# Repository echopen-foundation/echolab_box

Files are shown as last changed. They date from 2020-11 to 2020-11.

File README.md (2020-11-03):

---

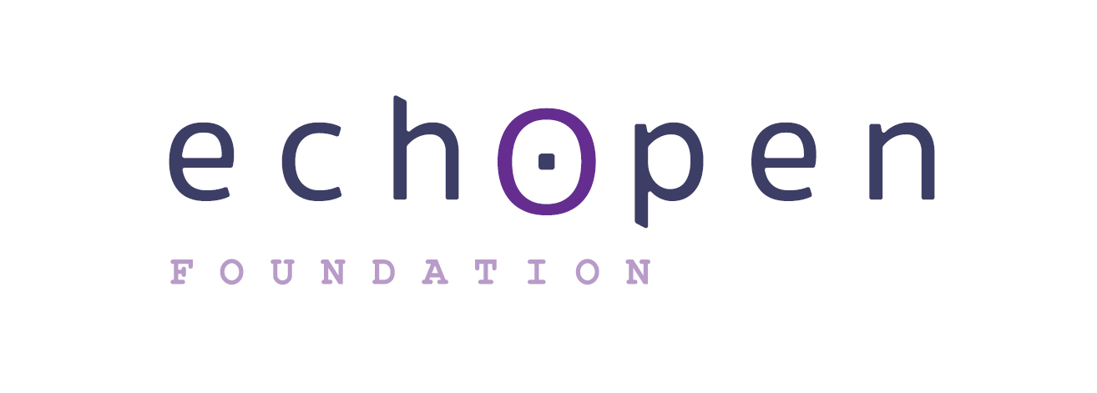
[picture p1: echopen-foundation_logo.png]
[](http://www.echopen.org)

---

# echʘlab Box

This project presents box containing all necessary components to play with ultrasound.

Find source files here : https://github.com/echopen-foundation/echolab_box

Find documentation here : https://github.com/echopen-foundation/echolab_box/wiki

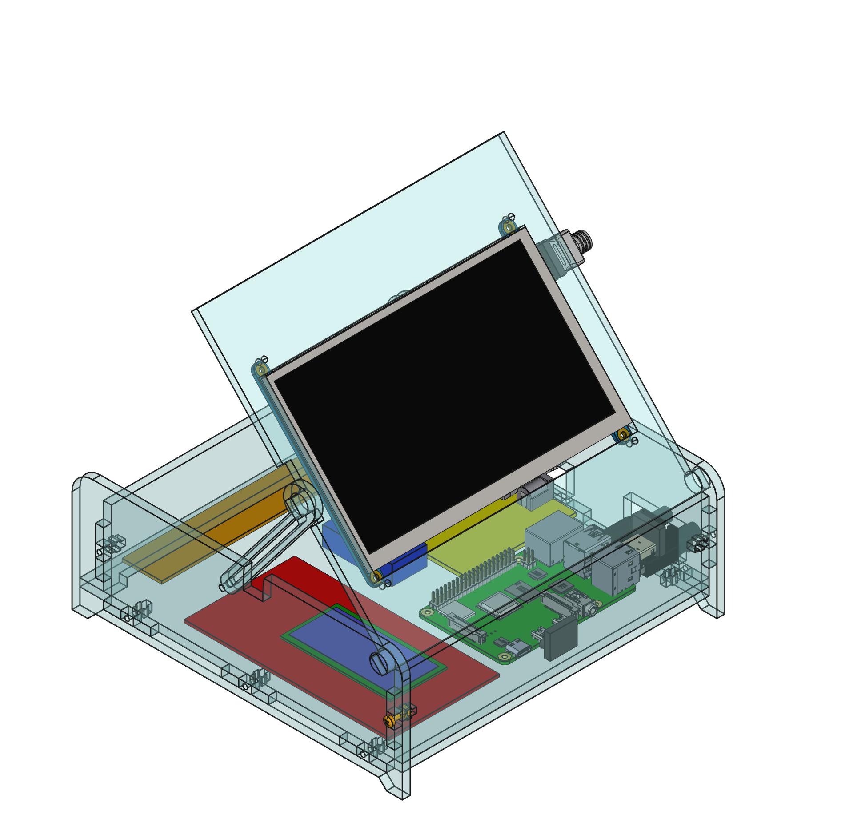
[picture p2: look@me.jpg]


---

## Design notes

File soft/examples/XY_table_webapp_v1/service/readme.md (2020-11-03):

# Installation as a service

from : http://www.diegoacuna.me/how-to-run-a-script-as-a-service-in-raspberry-pi-raspbian-jessie/
and : https://wiki.archlinux.org/index.php/systemd

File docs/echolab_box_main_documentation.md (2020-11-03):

# echolab_box

## Introduction

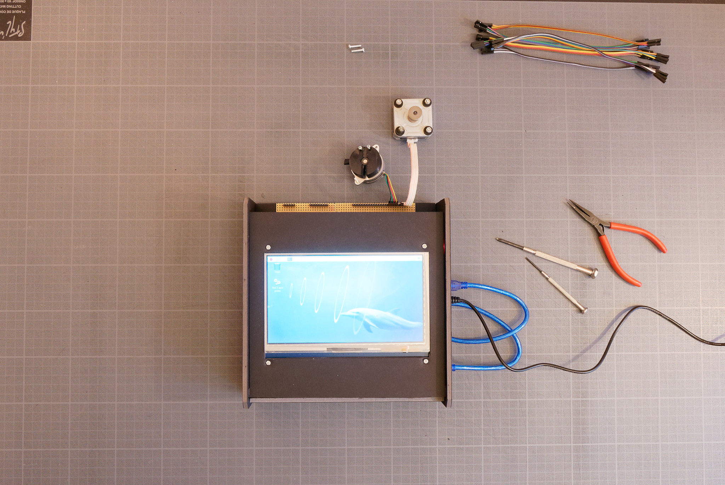
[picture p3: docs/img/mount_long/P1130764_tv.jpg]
Main Picture


| Prerequisite | None |
| :--- | --- |
| **Duration** | 1/2 day |
| **Cost** | 800 - 900 € |
| **Open-source License Software** | BSD3 License |
| **Open-source License Hardware** | EchOpen License |

echolab_box is the first step of the echolab project by echOpen. The idea of echolab (EchOpen Lab Kit) project is to capitalize on all the previous contribution of the community and design an open-source modular hardware  "EchOpen Lab Kit" which enable everyone to make their own acoustic, software and firmware experiment. We want to develop a full range of components compatible and combinable with one another in order to build a custom lab. echolab_box is the core module conceived as a test bench on which you can plug devices such as 2D table, custom ultrasound card, custom transducers...

## Design files

The only design files needed to build echolab_scope are the casing files as all the other component are mechanic or electronic parts available on the market.

| Title  | Original files | Reading files | Design tool |
| --- | --- | --- | --- |
| Casing | [Link to originals](../meca/echolab_box_v3.fcstd) | [Link to reading files](../meca/build/casing_to_print.pdf) | [FreeCad](https://www.freecadweb.org/?lang=fr) |

*Original files: files used to make modifications on the project*

*Export files: files that can be opened and imported by other programs or softwares (STEP, IGES...)*

*Reading files: files used to study or produce without modifications (PDF, STL...)*

## Software and firmware

| Source code | Compilation process | State |
| --- | --- | --- |
| [echolab_box/soft/src](../soft/src) | Python 3 | In progress |

## Nomenclature

| Designation | Quantity | Description | Supplier  | Price/unit (€ TTC) | Datasheet |
| --- | --- | --- | --- | --- | --- |
| Software Controller  | 1 | Controller Rpi - 4GB | LetMeKnow | 69 | [Link to datasheet]([https://letmeknow,fr/shop/fr/cartes-officielles/1782-raspberry-pi-4-4gb-4053199971756,html](https://letmeknow.fr/shop/fr/cartes-officielles/1782-raspberry-pi-4-4gb-4053199971756.html)) |
| Touch screen | 1 | Screen waveshark 7 inch Capacitive Touch Screen HDMI LCD 1024 * 600 | Amazon | 60,96 | [Link to datasheet](https://www.amazon.fr/waveshare-Capacitive-Touchscreen-Display-LCD/dp/B07PK26D9H/ref=sr_1_6?__mk_fr_FR=ÅMÅŽÕÑ&keywords=screen%2B7%2Bhdmi&qid=1568879840&s=gateway&sr=8-6&th=1) |
| Ultrasound card | 1 | Ultrasound card open-source | echOpen | 600 | |
| CNC card | 1 | CNC card KEYESTUDIO Grbl Blister CNC carte contrôleur DIY | Amazon | 21,59 | [Link to datasheet](https://www.amazon.fr/keyestudio-contrôleur-Microcontrôleur-automatique-Fantasque/dp/B07D8LN386/ref=sr_1_17?__mk_fr_FR=ÅMÅŽÕÑ&keywords=cnc+shield&qid=1568881247&s=gateway&sr=8-17) |
| 5V Down power supply | 2 | 5V regulator DFR0571 3 A maxi | GoTronic  | 3,7 | [Link to datasheet](https://www.gotronic.fr/art-regulateur-5-vcc-dfr0571-29558.htm) |
| 12V Power supply | 1 | 12V Power supply | | | |
| Connections | 1 | HDMI display | Adafruit  | 5,88 | https://www,adafruit,com/product/3549 |
| Connections | 1 | HDMI RPi | Adafruit  | 5,88 | https://www,adafruit,com/product/3557 |
| Connections | 2 | Wire 20 cm | Adafruit  | 1,76 | https://www,adafruit,com/product/3561 |
| Connections | 2 | µUSB display and RPi | Adafruit  | 4,48 | https://www,adafruit,com/product/4105 |
| Connections | | PCB connector | | | |
| Casing | | Casing | | | |
| Fasteners | | Fasteners | | | |

## Assembly

| List of tools needed | Where to find it? |
| --- | --- |
| Screw driver | *(Optional)* |
| In Progress... | |

| Picture | Assembly instructions |
| --- | --- |
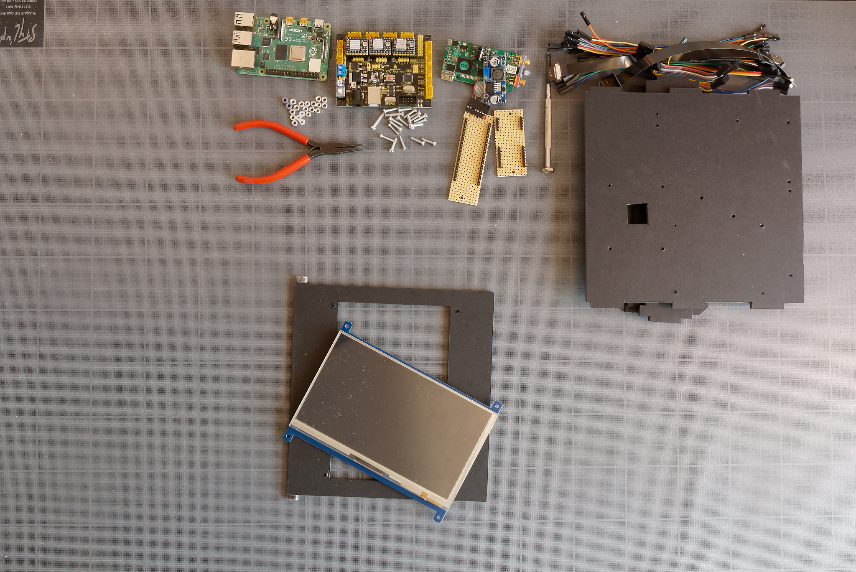
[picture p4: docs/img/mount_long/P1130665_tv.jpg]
Step 1 Picture
|  | Hardware components  We are using M2.5x12 screws and M2.5 nuts for all the assembly |
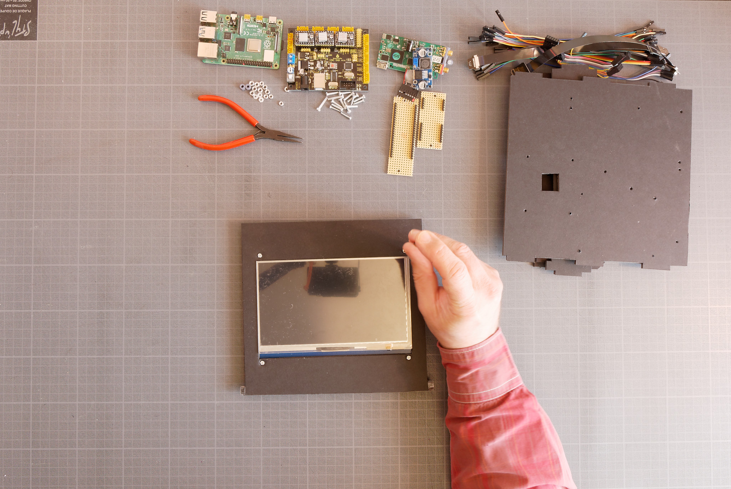
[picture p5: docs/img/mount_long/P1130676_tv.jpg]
Step 2 Picture
|  | Mount the touch screen on the top part of the box |
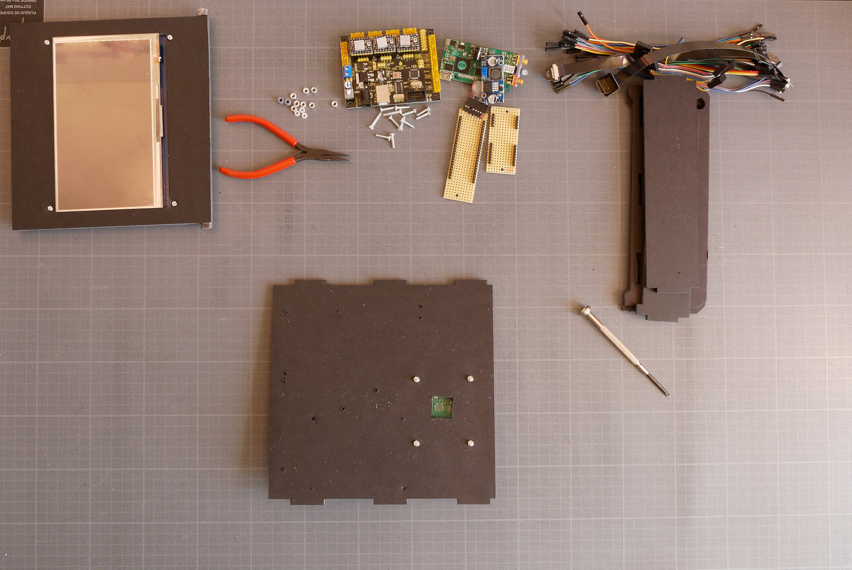
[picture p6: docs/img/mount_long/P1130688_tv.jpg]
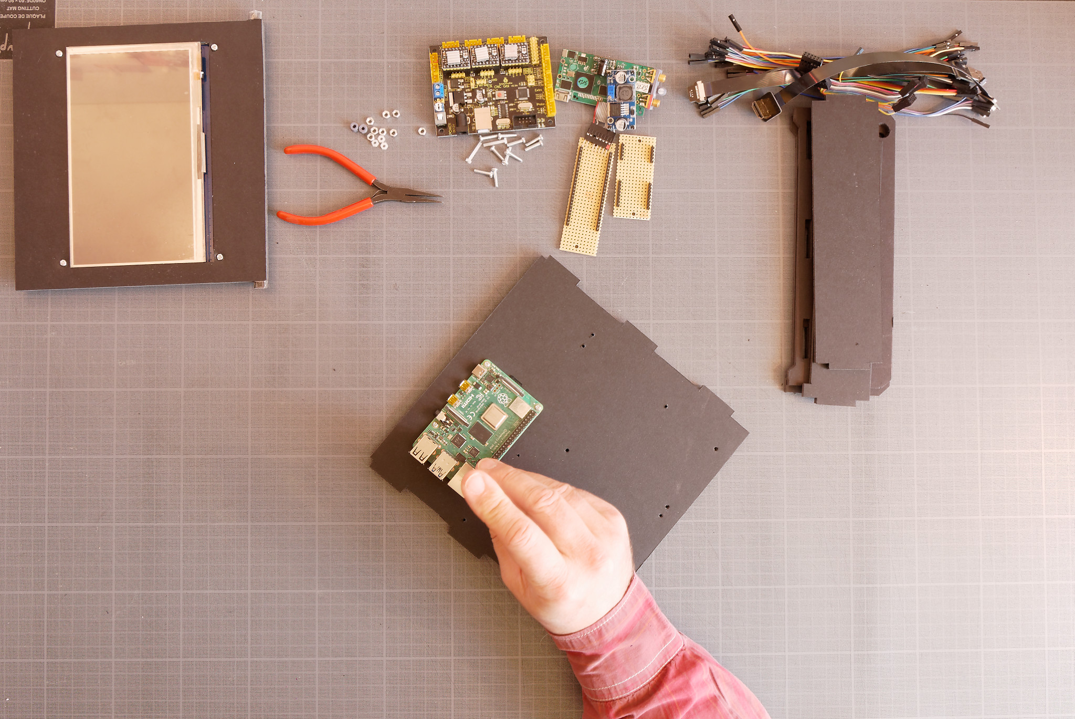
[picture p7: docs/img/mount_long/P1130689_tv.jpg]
|  | Mount the Raspberry Pi controller on the base of the casing |
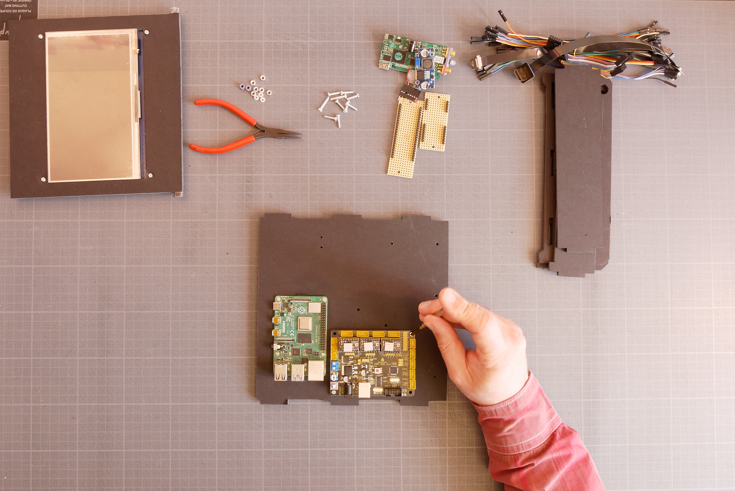
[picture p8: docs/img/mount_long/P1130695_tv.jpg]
Step 4 Picture
|  | Mount the CNC card |
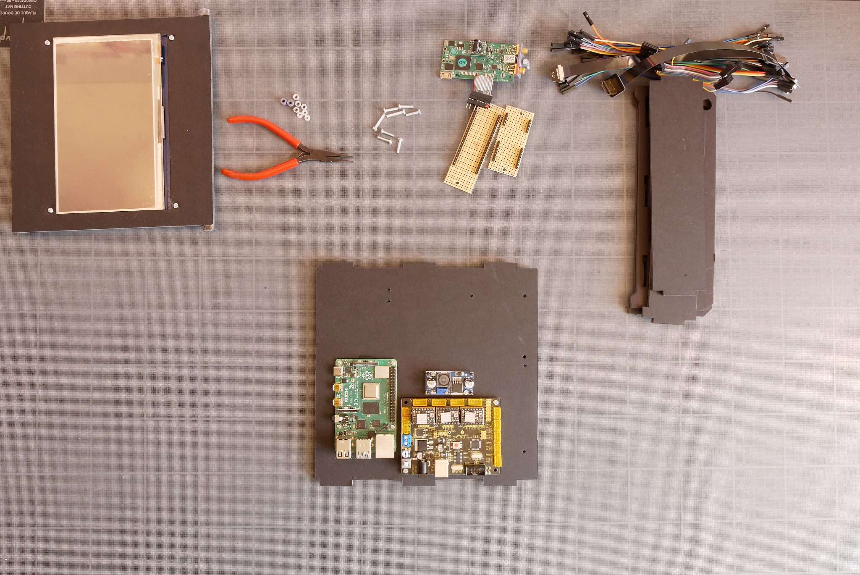
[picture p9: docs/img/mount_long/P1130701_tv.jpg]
Step 5 Picture
|  | Mount the 5V Step down power supply |
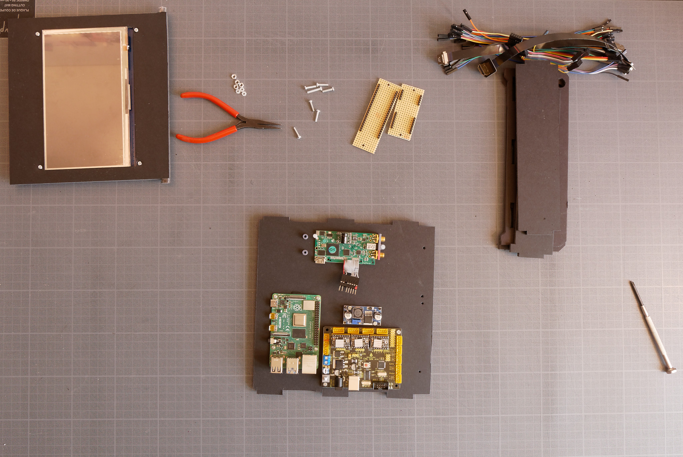
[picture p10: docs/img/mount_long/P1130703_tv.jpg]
Step 6 Picture
|  | Mount the ultrasound card. This model is a US SPI (can be replaced by another open-source model) |
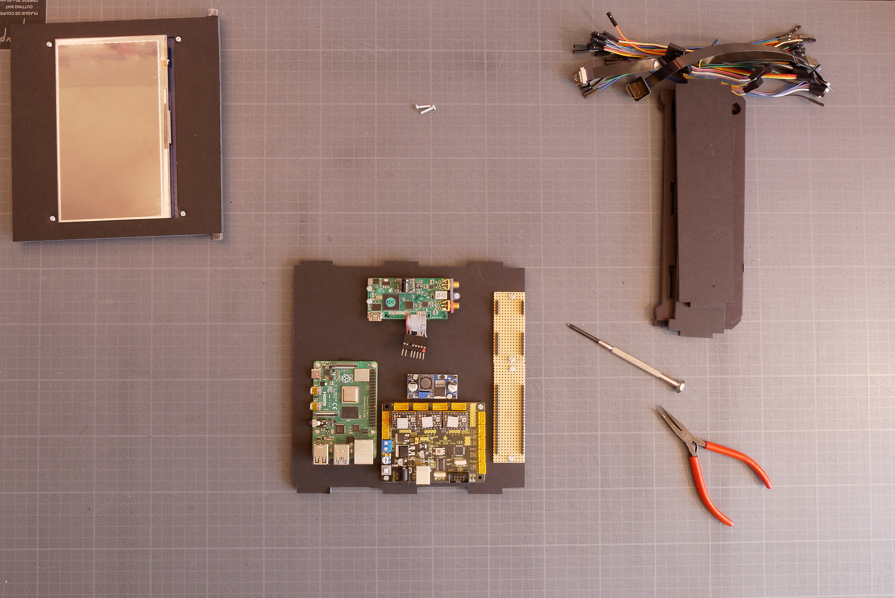
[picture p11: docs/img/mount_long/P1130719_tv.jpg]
Step 7 Picture
|  | Mount the connector board |
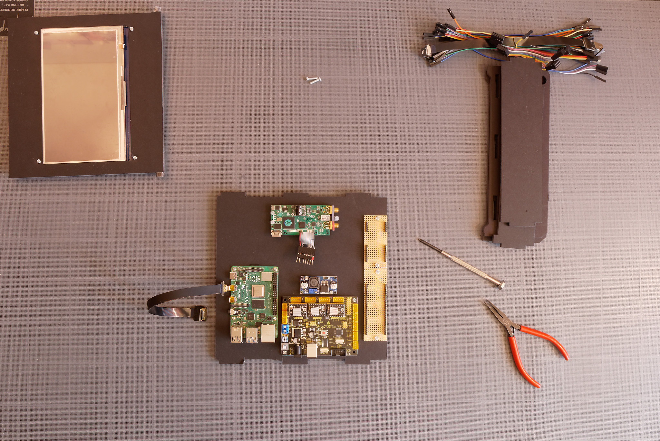
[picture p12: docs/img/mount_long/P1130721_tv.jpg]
Step 8 Picture
|  | Connect the HDMI wire to the Raspberry Pi |
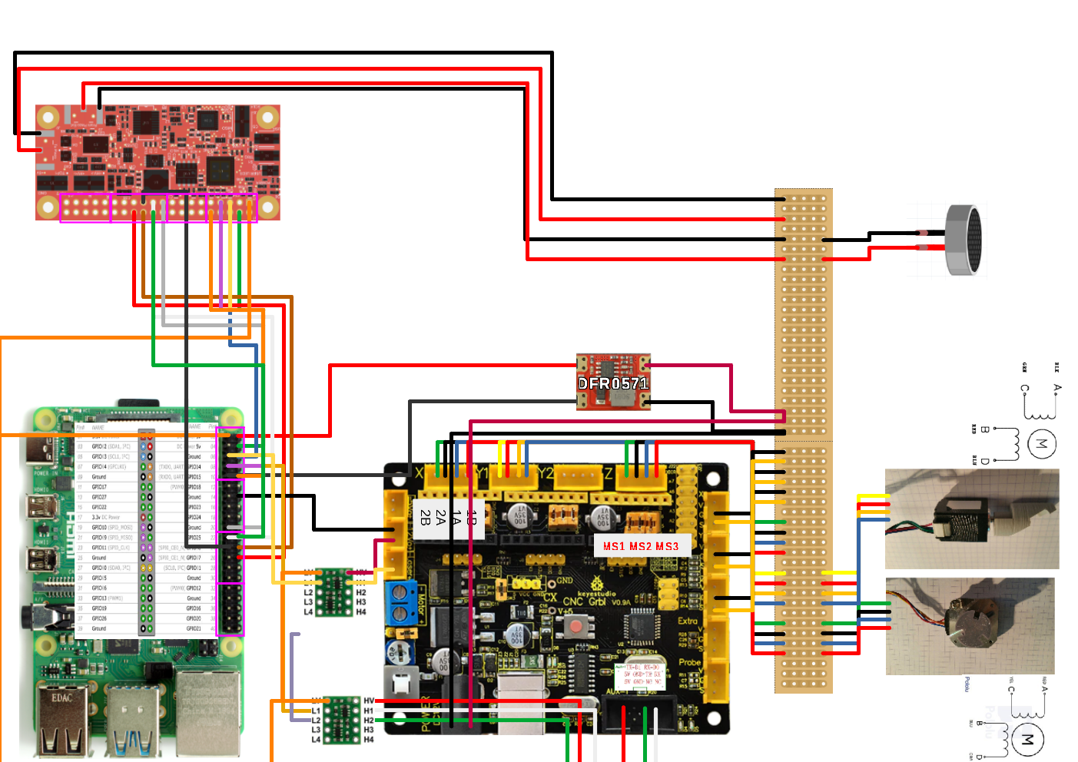
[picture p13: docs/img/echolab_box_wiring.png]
Step 9 Picture
|  | We are now going to connect all the components following this wiring scheme |
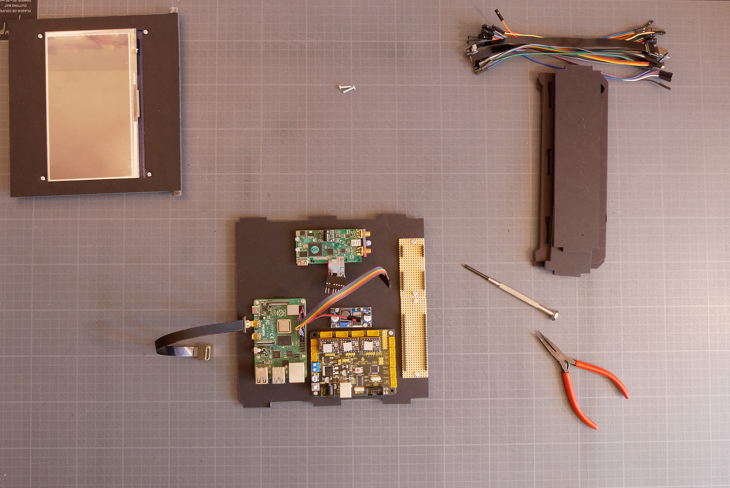
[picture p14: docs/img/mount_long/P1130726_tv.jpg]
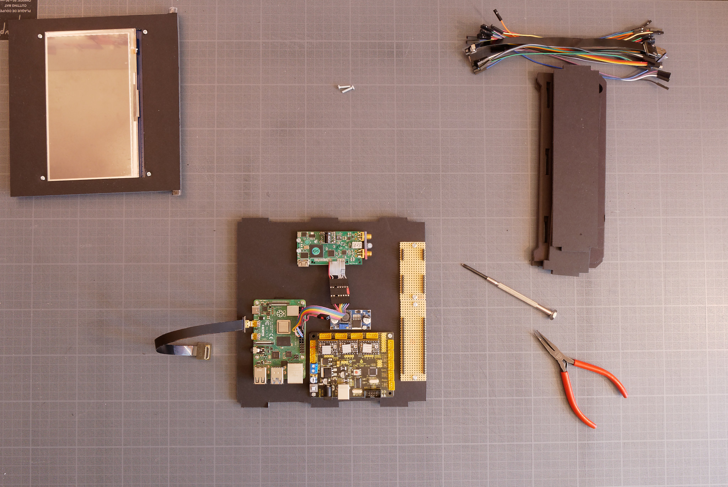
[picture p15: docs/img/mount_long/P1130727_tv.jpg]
|  | Connect the RPi to the ultrasound board |
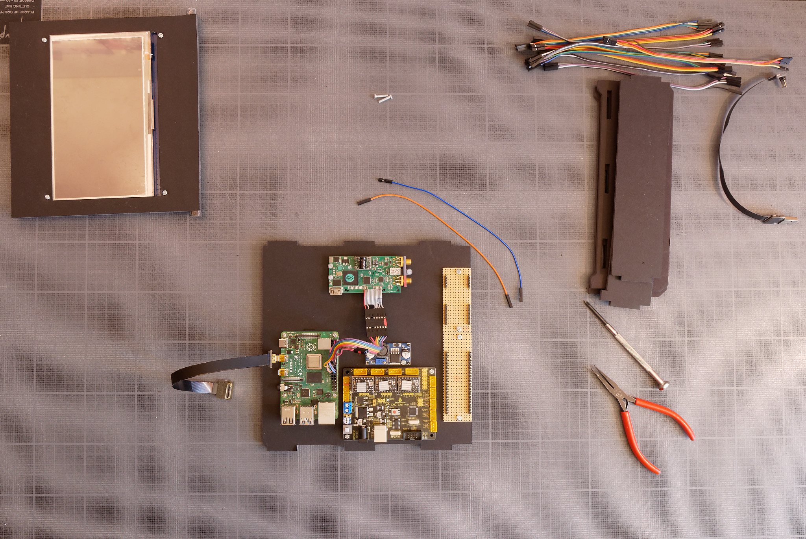
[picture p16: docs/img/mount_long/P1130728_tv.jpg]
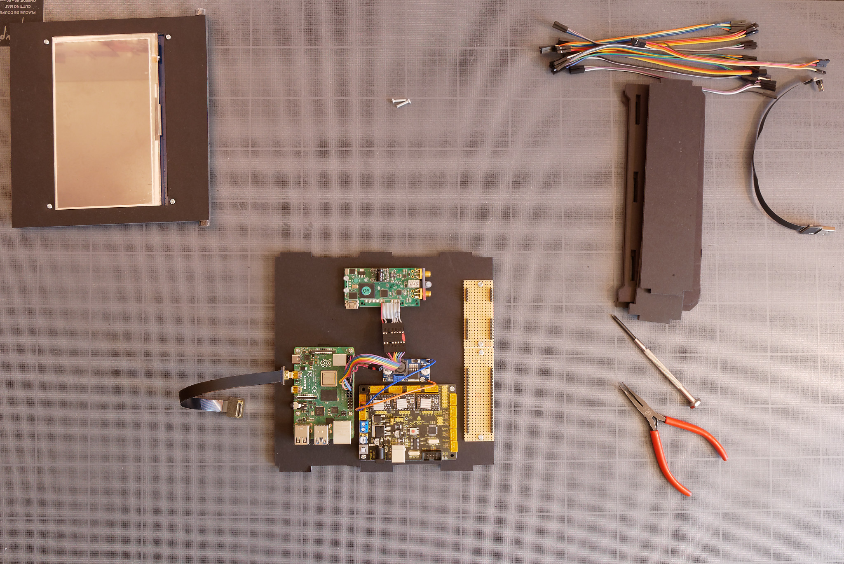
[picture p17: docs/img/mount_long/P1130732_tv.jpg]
|  | Then connect the CNC card to the 5V Step down power supply |
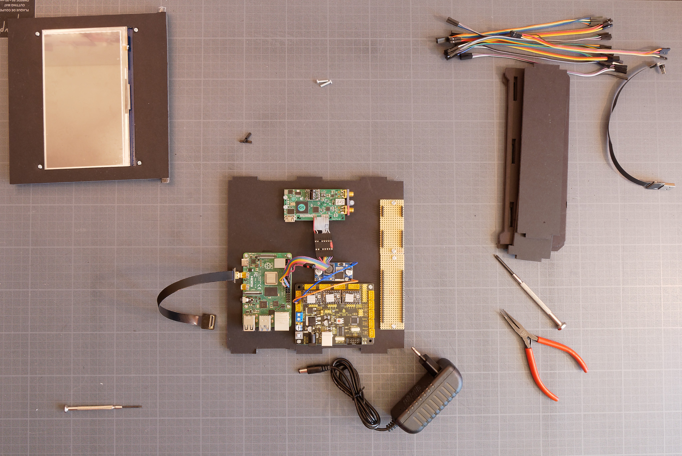
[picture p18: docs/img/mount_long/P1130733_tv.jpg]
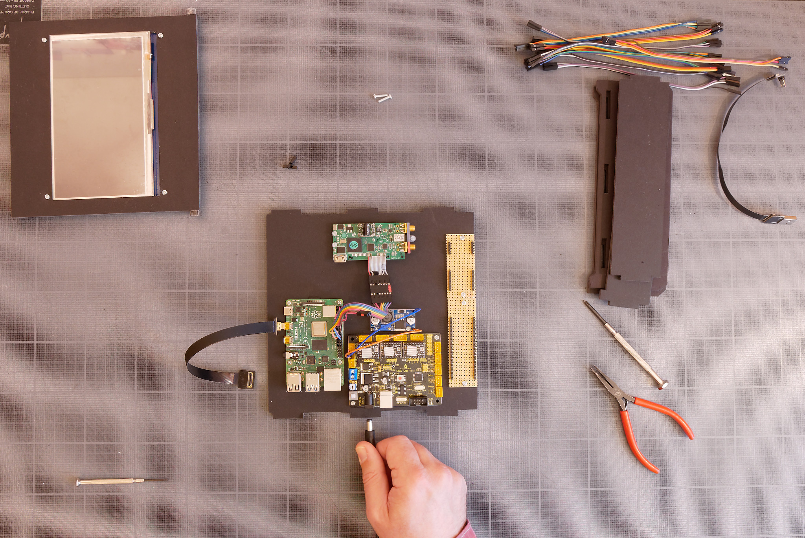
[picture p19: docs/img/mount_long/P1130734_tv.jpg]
|  | Connect the 12V Power supply to the CNC card |
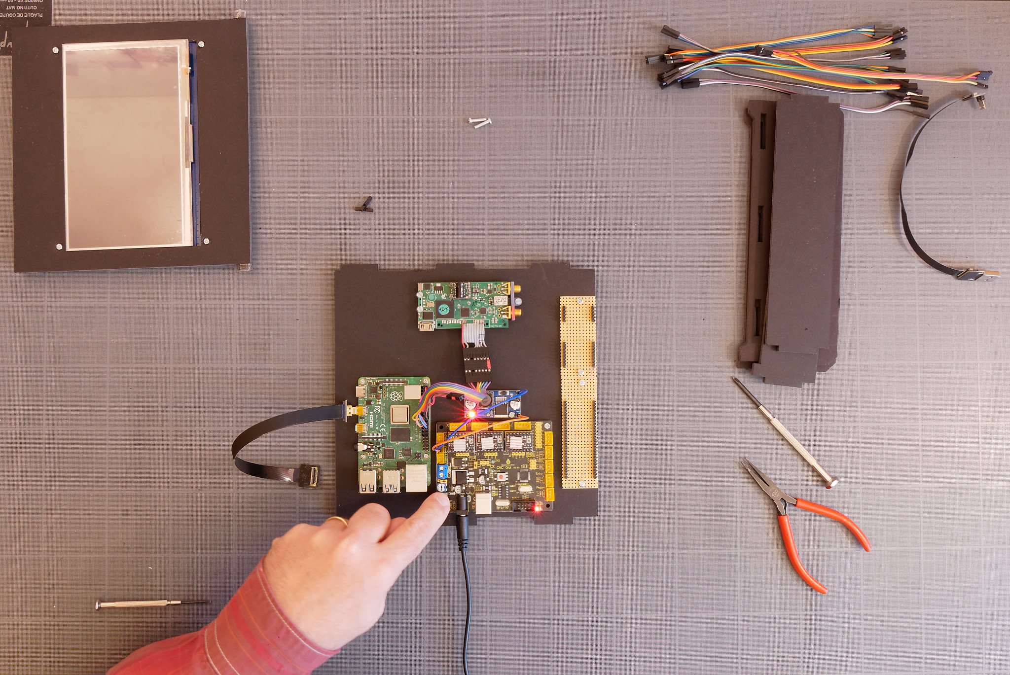
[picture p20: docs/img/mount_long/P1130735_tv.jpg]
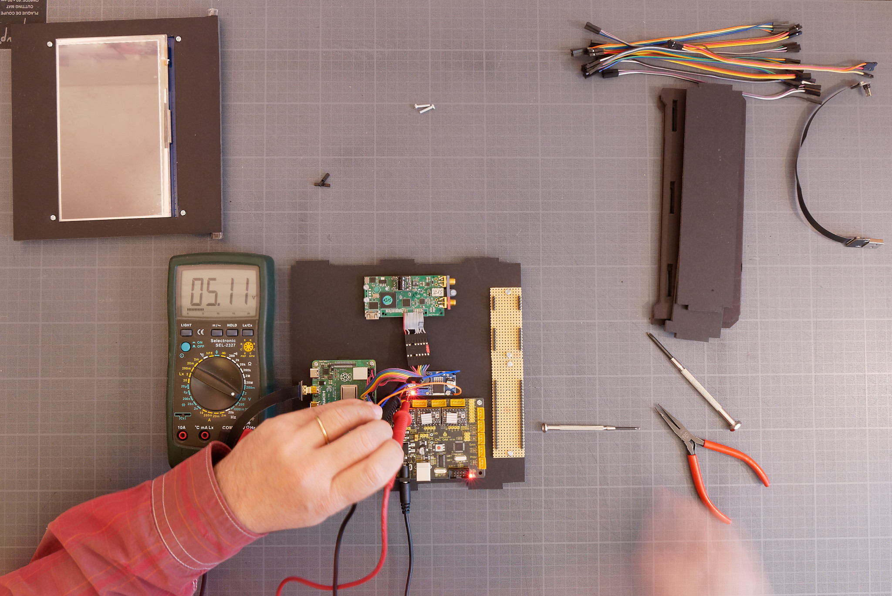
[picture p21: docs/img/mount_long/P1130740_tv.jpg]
|  | Set the Step down power supply to 5V prior to connect the RPi |
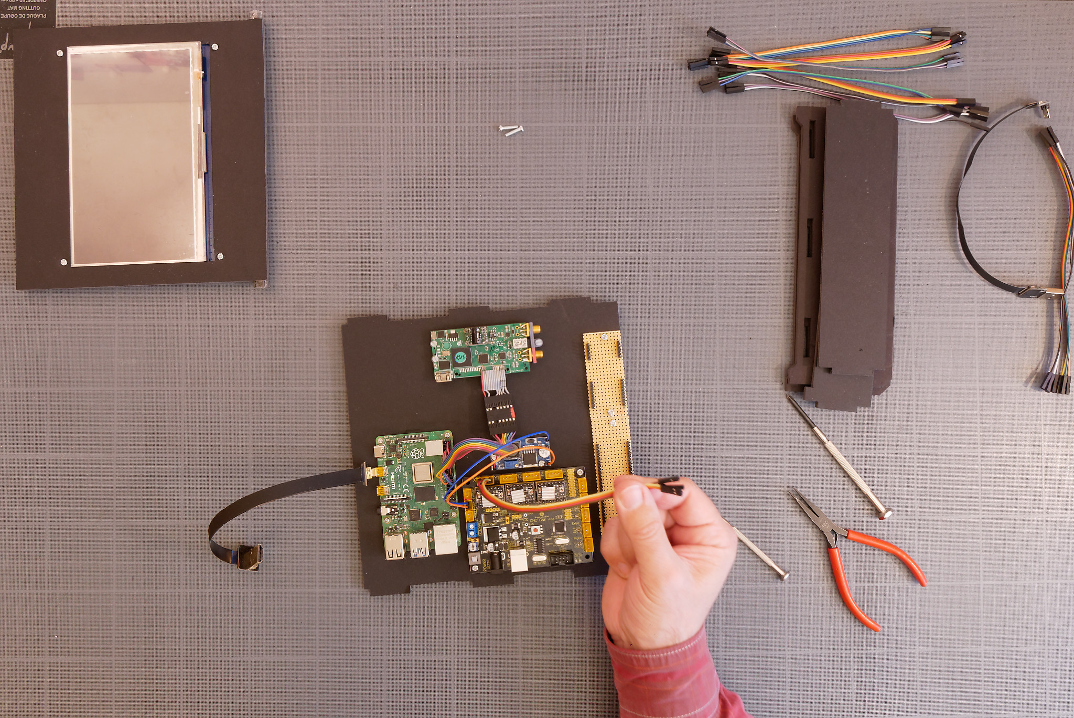
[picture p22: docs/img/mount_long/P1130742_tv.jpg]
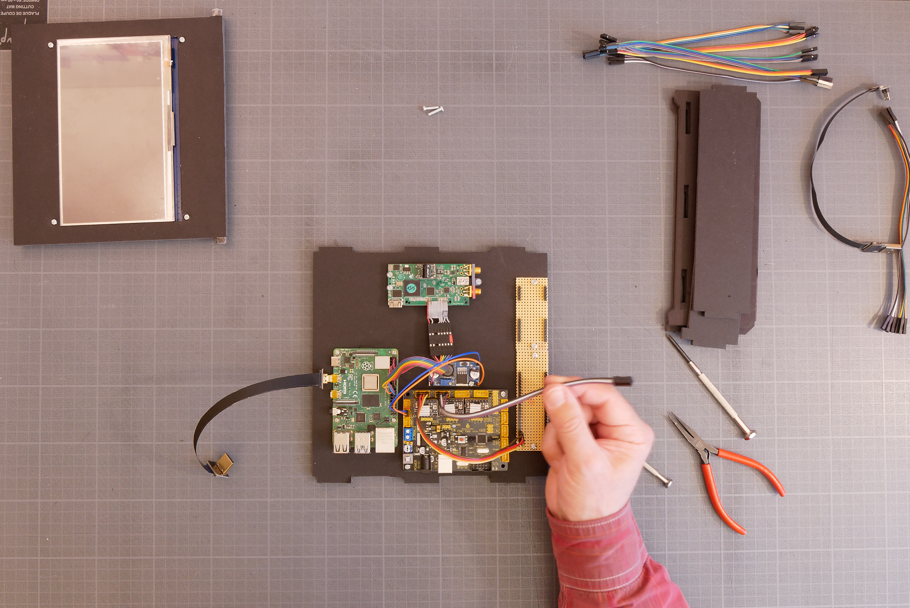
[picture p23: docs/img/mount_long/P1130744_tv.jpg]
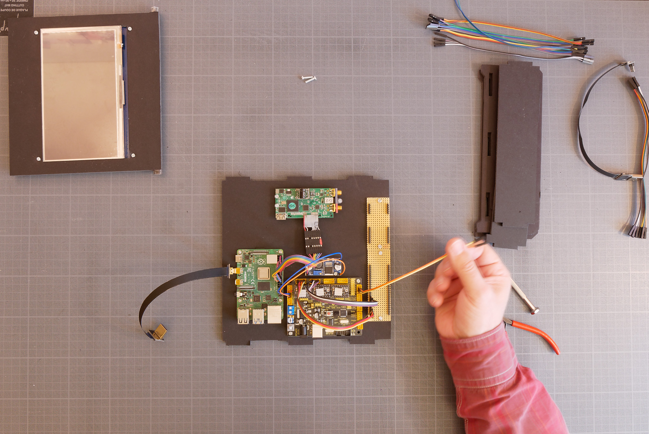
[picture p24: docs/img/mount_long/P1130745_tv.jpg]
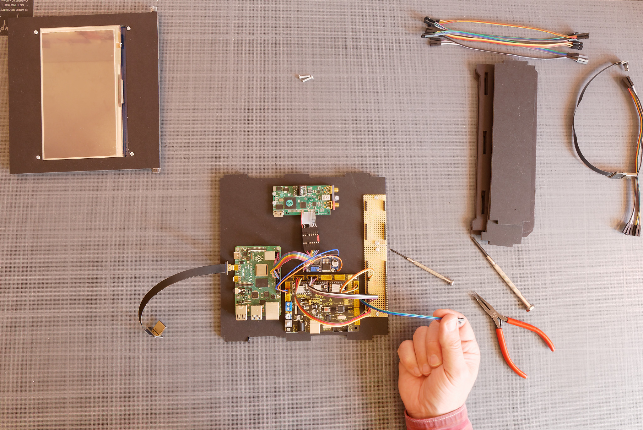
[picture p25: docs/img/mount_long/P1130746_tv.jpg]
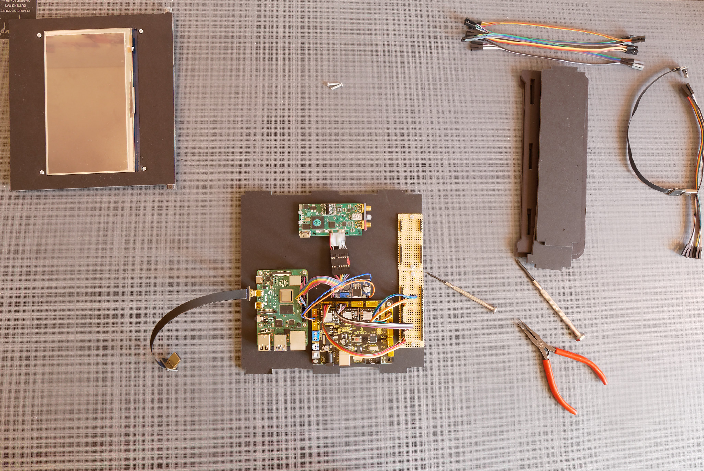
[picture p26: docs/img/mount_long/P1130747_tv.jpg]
|  | Connect stepper wires from CNC card to connector board |
| Step 15 PictureStep 15 PictureStep 15 PictureStep 15 PictureStep 15 PictureStep 15 Picture | Mount the casing parts and the touch screen |
| Step 16 PictureStep 16 PictureStep 16 PictureStep 16 Picture | Connect the screen and the RPi |

## Use

 Demo videot 

This video is showing a previous version of echolab_box

*Starting guide and operating instructions in progress ...*

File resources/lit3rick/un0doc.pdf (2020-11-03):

## UN0RICK: OPEN-SOURCE ULTRASOUND FPGA BOARD

A POLYGLOT DOCUMENTATION FILE

Luc Jonveaux∗
Tinkerer, Milly le Meugon, France contact@un0rick.cc

August 14, 2019

ABSTRACT

Non destructive testing and imaging ultrasound have been around since the ’50s. Many ultrasound open-source projects are emerging, mostly focusing on image processing - while hardware has been left behind. Several teams have produced successful designs to be used on commercial US scanners, but they are not cheap, and are difficult to access. I couldn’t find designs to play with, that would be affordable or open, so I decided to make one for makers, researchers and hackers.
This PDF is also a ZIP that contains the sources to the hardware and some data too, don’t hesitate to have a look. Just rename the file from .PDF to .ZIP and you’re ready to go .

Keywords open-source · ultrasound · hardware · ice40 · fpga

### 1 Overview

This wonderful board has been designed to provide a curious tinkerer with the basis to play with, and understand, ultrasound NDT and imaging bases.


Figure 1: What is on the board ?

∗More on the website http://un0rick.cc. This paper has its on Zenodo DOI 10.5281/zenodo.3364559 (http://doi.org/10.5281/zenodo.3364559)

UN0RICK DOCUMENTATION - AUGUST 14, 2019

It has not been designed with cost-efficiency, size optimization and having the lightest BOM - instead, it tries to be an understandable assembly of the different blocks that constitute a pulse-echo system : a High Voltage (HV) source, a pulser, a protection, a Time Compensation Amplifier, a good ADC, and, at the heart, a cheap but interesting FPGA to provide with all the controls and interfaces. There are also a couple of IOs, and some space for a Raspberry header - so that you can use with your favorite card-sized computer, but also with any chip with an available SPI bus.

### 1.1 Concept


That said, the board is based on a HX4K/HX8K FPGA, with plenty of
IOs broken out. It communicates with the outside world via an SPI bus, available either through USB with the on-board FTDI.

The FPGA is really at the heart of the platform, controlling pulser, ADC, TGC, interfacing with the high-speed RAM and the different IOs.

A benchmarking exercice showing that 50-80Msps ADCs were the norm, especially for piezos between 3 to 10MHz, I had to doubt puttign a 65Msps ADC onboard. Its 10 bits mean that I can use remaining bits on the 16-bit words to add in some information - always handy.
This platform has been used with NDT piezos, with regular piezos, and with vintage mechanical probes. It seemed to work with all - just be aware you may want to work on impedance matching sometimes, somehow.

### 1.2 What about the specifications of the board ?


Figure 2: Old news

FPGA: Lattice iCE40HX4K - TQFP 144 Package: use for quite a number of IOs, though no RAM, and compatibility with Clifford Wolf’s Yosys (http://www.clifford.at/yosys/) Open SYnthesis Suite [2].

Memory 8 Mbit SRAM, 10ns, 512 k x 16 (equivalent 65 full lines of 120us at 64Msps or 840 lines of 120us at 10Msps, 8 bits), as well as 8 Mb SPI Flash for FPGA configuration.

Ultrasound processing: A VGA (AD8331) controled by DAC, with a pulser: MD1210 + TC6320, and a 65Msps ADC (ADC10065).

Extensibility: 2 x PMOD connectors, two SMA plug for the piezos (with capacity to separate the TX and RX paths) as well as a general header for RPi GPIO

User Interfaces: 2 x PMOD for IOs, 3 push button (with software noise debouncing) and jumpers for high voltage selection

Input Voltage: 5 V from RPi or USB, uses 350mA-450mA at 5V with a raspberry on. The FPGA and logic operate at at 3.3 V, still with high voltage at 25V, 50V, 75V

### 2 Where to find the latest sources

Figure 3: NDT

The latest sources of the hardware as well as software are available at https://github.com/kelu124/un0rick/. (https://github.com/kelu124/un0rick/) However, this PDF also doubles as an archive (you can rename the .pdf as a .zip, and you’ll see), and contains, in short: a set of gerbers and BOM, some VHDL code, a basic FPGA binary ready to be used, and a python library to operate the board from a Raspberry Pi. There may be some other stuff there, but I forgot what I put there.

The hardware file is copied on GitHub, feel free to check it on UpVerter (https://upverter.com/design/kelu124/c59550d3e0dcf944/un0rick-v11/) though - thanks David!

### 3 Operation

Okay, we know the board now. But how is it operated? The usual flow of operation is to first flash the FPGA with the right "server", configure the acquisition details, get the signal, and to process it. Let’s see how to do it in more details.

### 3.1 Programming

The first thing is to program the FPGA with its binary. The recommended binary is attached in this archive (with a .bin extension). First is to use a computer with any FPGA programming capacity, such as diamond programmer or IceProg for

Linux. Don’t forget to setup the the jumper (see below) for FPGA update before connecting to the USB. The FTDI should appear in you device list. You’re then ready to program using your tool. The LED XXX should then be ready. The onboard flash will keep the binary in memory, so that’s something that needs to be done only once.


Figure 4: Programming the board

### 3.2 Preparing


Figure 5: Robotic arms

The platform can be set up with the SPI bus, to configure the different acquisition values as well as the TGC gain. (https://github.com/kelu124/echomods/blob/master/include/experiments/auto/20180721a.md) It using the following addresses and protocol (SPI is only 8bits per CS). For each address, one needs to send 0xAA 0xXX 0xYY, with XX the register address, and YY the data one wishes to send. Register addresses start at 0xE0 and end at 0xD0 on the default bitstream. The following can be programmed:

- Type of acquisition (one line / set of lines)
- Number of lines
- Length of lines acquisitions
- Delay between acquisitions
- Pulse width
- Delay between pulse and beginning of acquisitions
- 200us time-gain-compensation programmable (8 bits, from 0 to Max), every 5us


Figure 6: With an old
endo-cavity setup

For the TGC, the addresses start at 0x10 and end at 0x38. This corresponds to t = 0us for 0x10, and t = 200us for 0x38. Values that can be saved range from 0 to 8 bits for full amplification.

The LED 6 is linked to the multi/single line status. Therefore, it is easy to check if the FPGA is ready to shoot: one can toggle the register to check if the LED blinks. It is done in pyUn0 with the test_spi from the us_spi class, by typing python pyUn0.py test.

The pyUn0 lib for example provides a wrapper to easily manipulates an acquisition set of parameters with a Raspberry (one just needs to leave the jumper on from Fig 3), you can also find code for an exercice of using an ESP32-based M5Stack board (check out the esp32_prog.ino file in the archive).

The python lib also provides access to objects that can be manipulated, including the time, all metadata, the signal itself, and allows for preprocessing the data according to the metadata (for example filtering the signal given the frequency and bandwidth of the element used).

### 3.3 The registers

Address | bitsize | Description | Default value | Unit | Value
0xE0 | 8 | Lengh of Pon | 0x14 | 1/128us | 200 ns
0xD0 | 8 | Lengh between Pon and Poff | 0x0A | 1/128us | 100 ns
0xE1 | 8 | Lengh of Poff MSB
0xE2 | 8 | Lengh of Poff LSB | 0xC8 | 1/128us | 2000 ns
0xE3 | 8 | Delay between Poff and Acq (MSB) | 0x02BC | 1/128us | 7000 ns
0xE4 | 8 | Delay between Poff and Acq (LSB)
0xE5 | 8 | Lengh of acquisition MSB | 0x32C8 | 1/128us | 130 us
0xE6 | 8 | Lengh of acquisition LSB
0xE7 | 8 | Period of one cycle MSB | 0x186A0 | 1/128us | 1 ms
0xE8 | 8 | Period of one cycle 15 to 8
0xE9 | 8 | Period of one cycle LSB
0xEA | 1 | Software Trig : Auto clear | 0 | N/A
0xEB | 1 | 0: single mode 1 continuous mode | 0 | N/A
0xEC | 8 | Voltage gain control: 0V to 1V | 0x11 | 0,004 | 68 mV
0xED | 8 | Frequency of ADC acquisition | 0x03 | 64/(1+f) MHz | 16 MHz
0xEE | 8 | How many cycles in continuous mode | 0x0A | cycles | 10 cycles
0xEF | 1 | Sofware memory reset: set to 1; auto clear | 0

Table 1: The different registers in the current .bin binary

### 3.4 Acquiring and reading

If the master reads more data than the board has acquired, you will have old or incorrect values: the master has to know how many measures were done. The data is stored in RAM after the acquisition, for up to a 500k points depths. Again, the SPI bus is used to read the ADC value., by sending for example 0x00. If the FPGA is doing an acquisition, the returned value is 0xAA, else the value is on 2x8 bits, as follows:

- MSB: 8th bit: MSB ID: set to 1
- MSB: 6-7th bit: cycle bits: to identify a line in a sequence
- MSB: 4-5th bits: the two inputs (TopTurn 1 and TopTurn2) in case a counter is used.
- MSB: 1st-3th bits: ADC 7 to 9: 3 remaining bits of acquisition
- LSB: 8th bit: LSB ID: set to 0
- LSB: 1st to 7th bits: ADC 7-0: 7 first bits of acquisition

### 3.5 State of the art


Figure 7: The latest ultrasound news


On the first image, note the water bag for acoustic matching. On the last image, the tube holding the focused transducer ad a fairly narrow beam and a broad bandwidth signal response which allowed for high axial and lateral resolution. The transducer head could be in moved linearly back and forth or it could oscillate back in a polar rotation over about 120 degree angle, allowing visualization of biological structures that where in the field of view of the sound beam.

### 3.6 Processing using the pyUn0 python library

The objective of this last step is to transform the raw json, which contains the data as well as the metadata of the acquisition, into something that can be processed further - usually using Python.

Attached in this archive as well is a pyUn0.py file, as well as the data of an experiment, if you want to try. An example of this is shown in this video. (https://youtu.be/rv-Ag_TcnP8) The FPGA was already programmed. I simply used the pyUn0 wrapper by typing python pyUn0.py single to acquire a single line, followed by python pyUn0.py process, to process it. The result is as follows:


Figure 8: Results of the 20190804a experiment

The experiment files are also in the present archive - feel free to play with those.

### 3.7 Bonus

Interestingly, it is possible to reach a signal that is sampled at 128Msps - double of the maximum speed. Do you have an idea how this is achieved? Mail me and let me know!


Figure 9: Programming the board

### 4 Last details

License: This work is based on a previous TAPR project, the echOmods project. The un0rick project and its boards are open hardware and software, developed with open-source elements.

Copyright kelu124 (kelu124@gmail.com) 2018

- The hardware is licensed under TAPR Open Hardware License (www.tapr.org/OHL)
- The software components are free software: you can redistribute it and/or modify it under the terms of the GNU General Public License as published by the Free Software Foundation, either version 3 of the License, or (at your option) any later version.
- The documentation is licensed under a Creative Commons Attribution-ShareAlike 3.0 Unported License.

Disclaimer This project is distributed WITHOUT ANY EXPRESS OR IMPLIED WARRANTY, INCLUDING OF MERCHANTABILITY, SATISFACTORY QUALITY AND FITNESS FOR A PARTICULAR PURPOSE. See the GNU General Public License for more details. Also:

- This is not a medical ultrasound scanner! It’s a development kit that can be used for pedagogical and academic purposes - possible use as a non-destructive testing (NDT) tool too, for example in metallurgical crack analysis.
- As in all electronics, be careful, especially with high-voltage.
- This is a learning by doing project, I never did something related: it’s all but a finalized product.
- Ultrasound raises questions. In case you build a scanner, use caution and good sense!

Certification This piece of hardware is also open-hardware certified, under ID FR000005. (https://certification.oshwa.org/fr000005.html)

### 5 Links to go further

- Come and chat : join the Slack channel (https://join.slack.com/usdevkit/shared_invite/MTkxODU5MjU0NjI1LTE0OTY1ODgxMDEtMmYyZTliZDBlZA)
- The full GitHub Repo (https://github.com/kelu124/un0rick) with more ongoing works : also a messy braindump with all experiments (https://github.com/kelu124/echomods/)
- The board’s Tindie shop (https://www.tindie.com/stores/kelu124/) to get it
- The project Hackaday page (https://hackaday.io/project/28375-un0rick-an-ice40-ultrasound-board) with more logs
- wlmeng11’s SimpleRick for a analog part board. (https://github.com/wlmeng11/SimpleRick) Clever use of RTL-sdr hardware for the acquisition !
- Check out the OSHWA certification link (https://certification.oshwa.org/fr000005.html) under reference FR000005
- Check out my previous work (https://openhardware.metajnl.com/articles/10.5334/joh.2/) on the topic of ultrasound modules [1] and its dataset on Zenodo. (http://doi.org/10.5281/zenodo.377054)

### 6 Next steps

Plenty to do on the next steps! Let me know if you’d like to contribute. The current shopping list (non-exhaustive) may include:

- Improving the documentation, and prepare the work of the small sibling, lit3rick. (https://github.com/kelu124/lit3rick)
- Work on BOM costs and overall hardware design.
- Increase the high voltage source, and have it settable via an on-board, and ideally have a bipolar design. Including a new pulser chip as being tested on the lit3rick board, an up5k design that’s getting ready.
- Improving the features of the onboard firmware.. and try to develop a VGA output !
- Work on the FTDI - so I have only used the RPi, and write something to program the flash from the RPi.
- Develop a small server on the host RaspberryPi to manage the board and deliver to several possible users.

References

[1] Luc Jonveaux 2017. Arduino-like development kit for single-element ultrasound imaging. In Journal of Open Hardware, 1(1), p.3. DOI: 10.5334/joh.2 (http://doi.org/10.5334/joh.2)
[2] Clifford Wolf, Johann Glaser. Yosys - A Free Verilog Synthesis Suite. Website at http://www.clifford.at/yosys/

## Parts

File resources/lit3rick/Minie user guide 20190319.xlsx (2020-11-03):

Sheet: User guide
minie Board
20180222
 |  |  |  |  |  |  |  |  | 7.8125
Configuration
SPI | To configure the FPGA use the following addresses and protocol
 | SPI is only 8bits per CS
for each address:
 | Send | 0xAA | to access parameters
Followed by | Send | @ | parameter address 8bits
Followed by | Send | Data | Parameter 8bits
Read
Spi | To read the ADC value
SPI is only 8bits per CS
Master send 0
If the FPGA is doing in acquisition the return value is 0xAA
Else the value is on 2 times 8bits
MSB |  |  |  |  | LSB
MSB ID | Cycle number | TopTurn2 | TopTurn1 | ADC9-7 | LSB ID | ADC7-0
1 | 2 bits | 1 bit | 1 bit | 3 bits | 0 | 7 bits
Cycle number | In continious mode this represent the 2 lsb of the cycle counter
 | useful to separate the data of each cycle
If the master read more data than acquire it will return old values or incorrect value
the master has to know how many measures where done
Standart sequence
1 | Use Rpi or Computer:Connect
2 | Configure the jumper according to SPI master choice(USB or Rpi)
3 | power up via USB cable
4 | Send to FPGA the configuration registers via SPI
4 | Set the register EF to initiliaze memory(read and write pointers at 0)
4 | Trig via software or hardware
4 | Do a spi transaction and ignore the data received
4 | read the measures via SPI
Update FPGA
1 | Use a PC with diamond programmer
2 | Configure th jumper for FPGA update
3 | Connect the USB
4 | Program via the diamong programmer application
5 | The LED program shall be ON when ok.
Solution To use computer to communicate
The board has a FTDI ft2232H usb to SPI.
you can use a python program with the pyftdi library |  |  |  | https://pypi.python.org/pypi/pyftdi |  |  | and doc: | http://eblot.github.io/pyftdi/
You should install the depedencies before using this libray; see the doc
This diver is for the moment only half duplex- cannot read and write in the same transaction. FPGA don't use this. There is no issue.
sample.py
from binascii import hexlify
from pyftdi.ftdi import Ftdi
from pyftdi.spi import SpiController
from sys import modules, stderr, stdout
# Instanciate a SPI controller
spi = SpiController()
# Configure the first interface (IF/1) of the FTDI device as a SPI master
spi.configure('ftdi://ftdi:2232h/1')
# Get a port to a SPI slave w/ /CS on A*BUS3 and SPI mode 0 @ 12MHz
slave = spi.get_port(cs=1, freq=10E6, mode=0)
#to get the maximun frequency possible on this link
print(spi.frequency_max)
#to send a data
data_out = int(input('To send:'))
slave.write([data_out], True, True)
print(' sent:',data_out)
#to read a data
data_in = slave.read(1, True, True).tobytes()
data_in_hex = hexlify(data_in).decode()
print('\In = ',data_in_hex)
#The cs shall be manual - use of I/O4
gpio = spi.get_gpio()
gpio.set_direction(0x0800, 0x0100)
gpio.write(0x0100)
#before exchange
gpio.write(0x0000)
#after exchange
gpio.write(0x0100)
Configuration DAC variation
SPI | To configure the dac values every 5us use the following addresses and protocol
 | SPI is only 8bits per CS
for each address:
 | Send | 0xAA | to access parameters
Followed by | Send | @ | parameter address 8bits
Followed by | Send | Data | Parameter 8bits
Address in Hex | after in us | size in bits
10 | 0 | 8
11 | 5 | 8
12 | 10 | 8
13 | 15 | 8
14 | 20 | 8
15 | 25 | 8
16 | 30 | 8
17 | 35 | 8
18 | 40 | 8
19 | 45 | 8
1A | 50 | 8
1B | 55 | 8
1C | 60 | 8
1D | 65 | 8
1E | 70 | 8
1F | 75 | 8
20 | 80 | 8
21 | 85 | 8
22 | 90 | 8
23 | 95 | 8
24 | 100 | 8
25 | 105 | 8
26 | 110 | 8
27 | 115 | 8
28 | 120 | 8
29 | 125 | 8
2A | 130 | 8
2B | 135 | 8
2C | 140 | 8
2D | 145 | 8
2E | 150 | 8
2F | 155 | 8
30 | 160 | 8
31 | 165 | 8
32 | 170 | 8
33 | 175 | 8
34 | 180 | 8
35 | 185 | 8
36 | 190 | 8
37 | 195 | 8
38 | 200 | 8

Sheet: Configuration
Name | Size in bits | Description | Address in Hex | Default value in hex | unit | Translation | <-Unit-> | Wanted | in HEX | To program
sEEDelayAll | 8 | Lengh before PHV | D0 | 2 | 7.8125ns | 15.625 | ns | 20 | 2 | 2 | 0 to To
sEEPHV | 8 | Lengh of PHV | E0 | 19 | 7.8125ns | 195.3125 | ns | 200 | 19 | 1B | DelayAll + PHV
sEEPHVpDamp1 | 8 | Lengh between Pon and Pdamp1 | D1 | C | 7.8125ns | 93.75 | ns | 100 | C | 27 | DelayAll + PHV + PHVPdamp1
sEEpDamp1 | 8 | Lengh of Pdamp1 | D2 | F | 7.8125ns | 117.1875 | ns | 120 | F | 36 | DelayAll + PHV + PHVPdamp1+ Pdamp1
sEEPDamp1nHV | 8 | Lengh between Pdamp1 and PnHV | D3 | C | 7.8125ns | 93.75 | ns | 100 | C | 42 | DelayAll + PHV + PHVPdamp1+ Pdamp1 + sEEPDamp1nHV
sEEPnHV | 8 | Lengh of PnHV | D4 | 19 | 7.8125ns | 195.3125 | ns | 200 | 19 | 5B | DDelayAll + PHV + PHVPdamp1+ Pdamp1 + sEEPDamp1nHV+PnHV
sEEPnHVPdamp2 | 8 | Lengh between PnHV and Pdamp2 | D5 | C | 7.8125ns | 93.75 | ns | 100 | C | 67 | DelayAll + PHV + PHVPdamp1+ Pdamp1 + sEEPDamp1nHV+PnHV+PnHVPdamp
sEEPdamp2 | 8 | Lengh of Pdamp2 MSB | E1 |  | 7.8125ns |  | ns
sEEPdamp2 | 8 | Lengh of Pdamp2 LSB | E2 | 100 | 7.8125ns | 2000 | ns | 2000 | 100 | 167 | DelayAll + PHV + PHVPdamp1+ Pdamp1 + sEEPDamp1nHV+PnHV+PnHVPdamp+Pdamp
sEEDelayACQ | 8 | Lengh of Delay between Pdamp and Acq MSB | E3
sEEDelayACQ | 8 | Lengh of Delay between Pdamp and Acq LSB | E4 | 380 | 7.8125ns | 7000 | ns | 7000 | 380 | 4E7 | DelayAll + PHV + PHVPdamp1+ Pdamp1 + sEEPDamp1nHV+PnHV+PnHVPdamp+Pdamp+DelayACQ
sEEACQ | 8 | Lengh of acquisition MSB | E5
sEEACQ | 8 | Lengh of acquisition LSB | E6 | 45a5 | 7.8125ns | 139.2890625 | us | 130 | 4100 | 45E7 | DelayAll + PHV + PHVPdamp1+ Pdamp1 + sEEPDamp1nHV+PnHV+PnHVPdamp+Pdamp+DelayACQ+ACQ
sEEPeriod | 8 | Period of one cycle MSB | E7
sEEPeriod | 8 | Period of one cycle 15 to 8 | E8
sEEPeriod | 8 | Period of one cycle LSB | E9 | 186A0 | 7.8125ns | 0.78125 | ms | 1 | 1F400 | 1F400 | Period
sEETrigInternal | 1 | Software Trig : Auto clear | EA | 0 | N/A |  |  | 0 | 0 | 0
sEESingleCont | 1 | 0: single mode 1 continious mode | EB | 0 | N/A |  |  | 0 | 0
sEEDAC_GAIN | 8 | Voltage gain control: 0V to 1V | EC | 11 | 0.004 | 0.068 | V | 0.5 | 7D
sEEADC_freq | 8 | Frequency of ADC acquisition | ED | 0 | 5ns+5ns | 64 | MHz | 64 | 0 | 0
sEETrigCounter 8LSB | 8 | How many cycles in countinious mode LSB | EE | A | cycles | 10 | Cycles | 10 | A
sEEpointerReset | 1 | Sofware memory reset: set to 1; auto clear | EF | 0
sEETrigCounter 8 MSB | 8 | How many cycles in countinious mode MSB | DE
sEEDAC_HV MSB | 2 |  | D6
sEEDAC_HV LSB | 8 | Voltage gain control: 0V to 1.22V | D7 | 0 | 0.002 | 0 | V | 20 | 13A | 13A | max 39V so 0x264 max
sHILO | 1 | Controle of HILO signal: value =HILO | D8
 |  |  |  |  | Number of measures to read |  |  |  | 8319
 |  |  |  |  | Total time for DAC variation |  |  |  | 139.2
 |  |  |  |  | number DACupdate DAC frequency |  | 5 | us | 27.84

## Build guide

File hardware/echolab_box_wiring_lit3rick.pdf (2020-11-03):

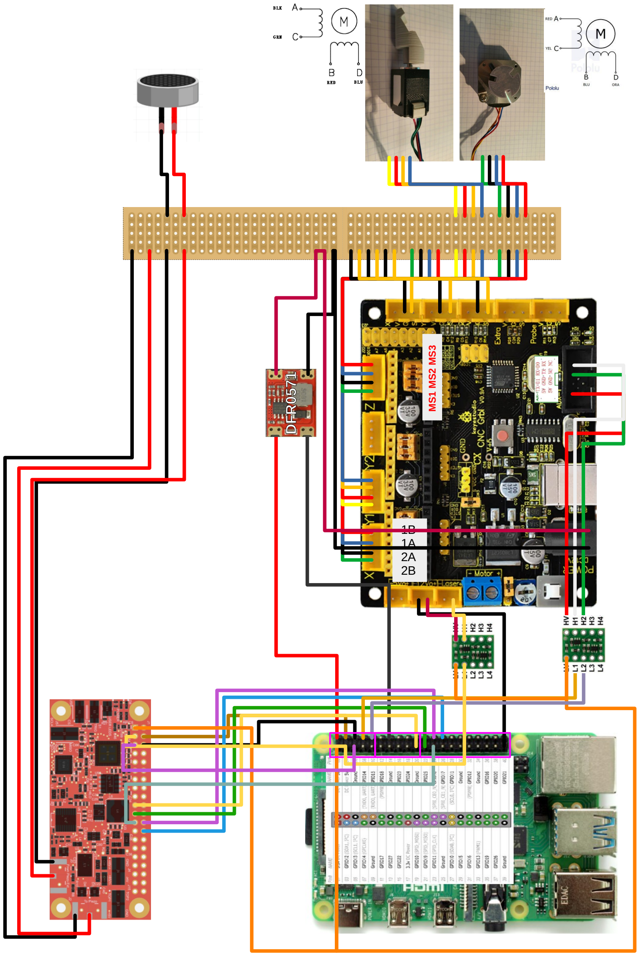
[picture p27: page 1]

1B
1A
2A
2B

MS1 MS2 MS3

## DFR0571

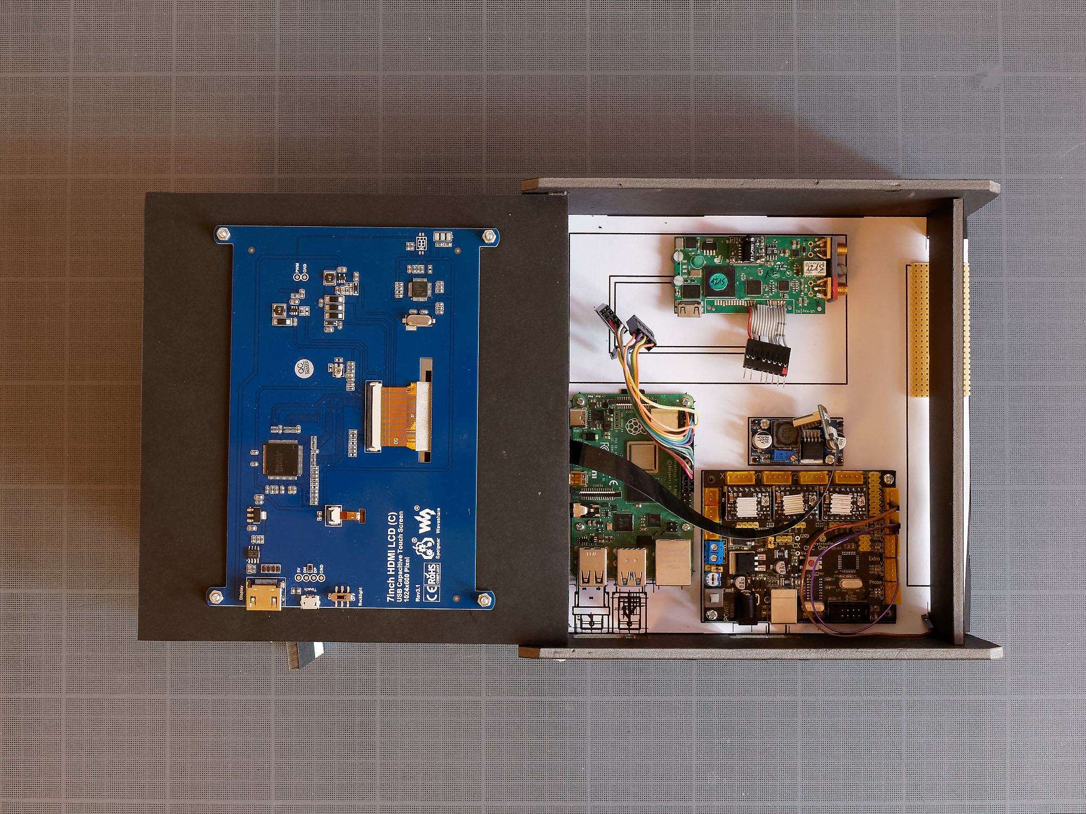
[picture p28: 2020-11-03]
docs/img/mount_short/echolab_box_step_17.jpg

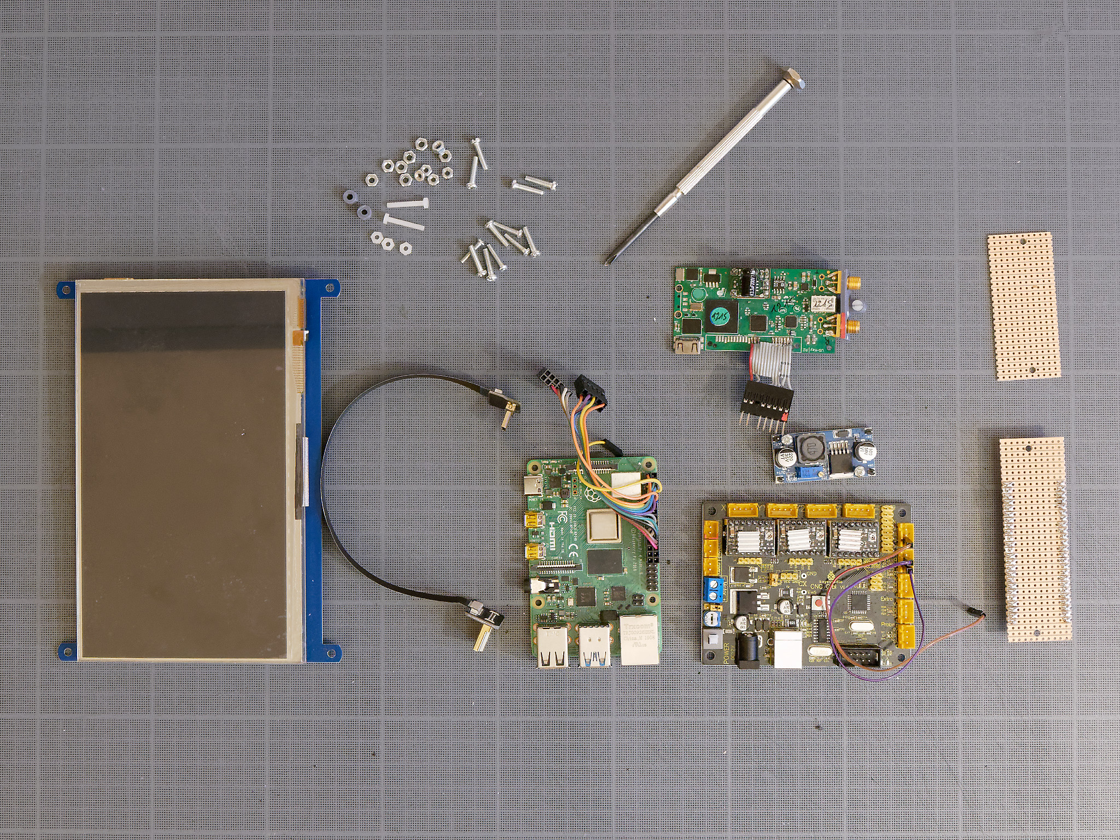
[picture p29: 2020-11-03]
docs/img/mount_short/echolab_box_step_02.jpg

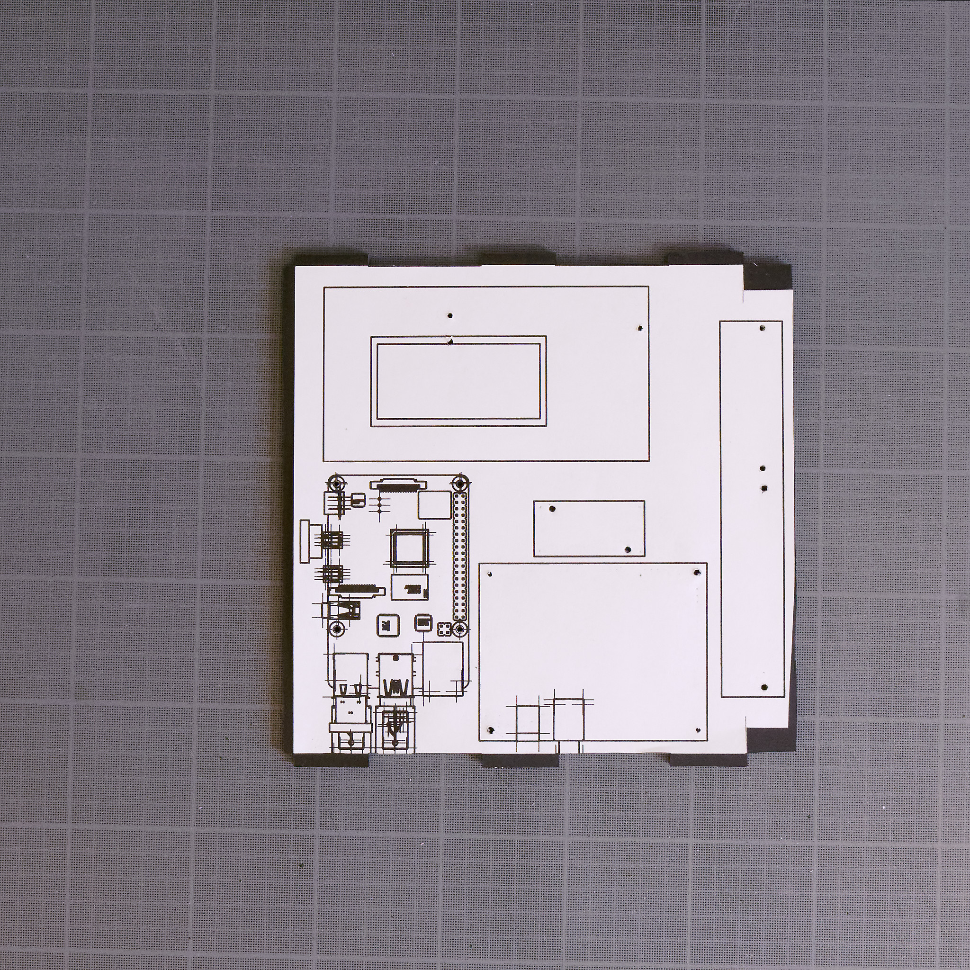
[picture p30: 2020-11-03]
docs/img/mount_short/echolab_box_step_04.jpg

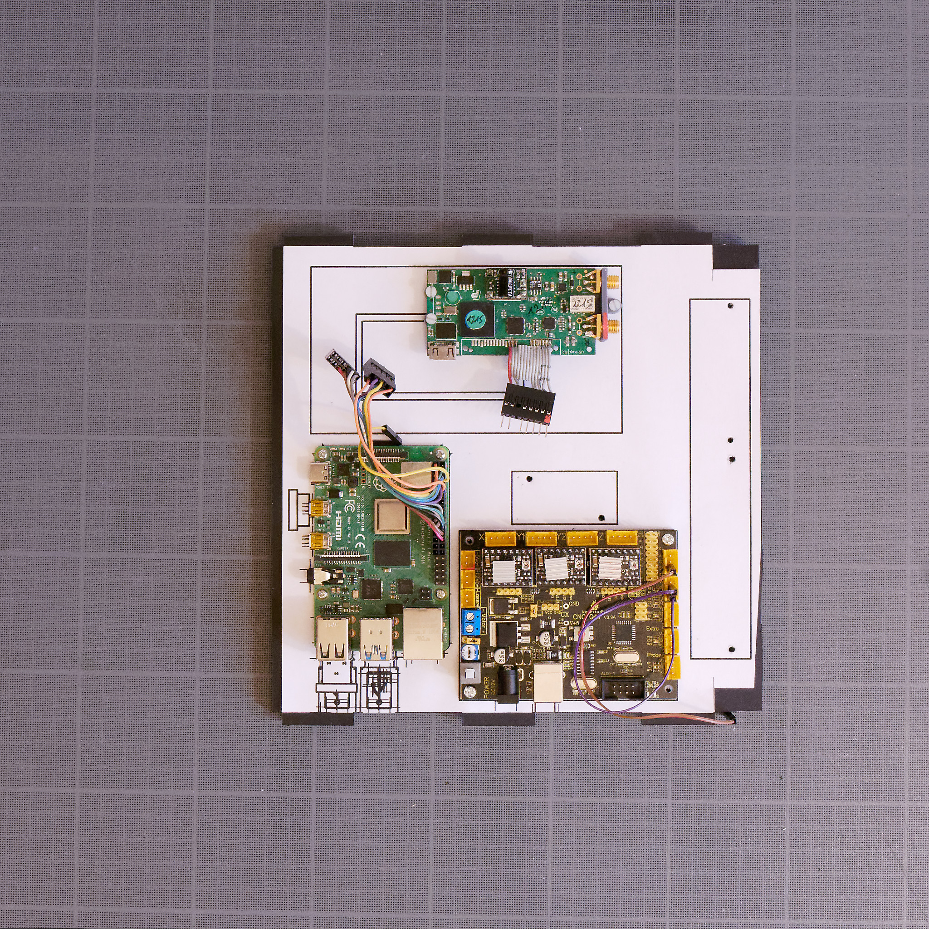
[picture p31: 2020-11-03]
docs/img/mount_short/echolab_box_step_07.jpg

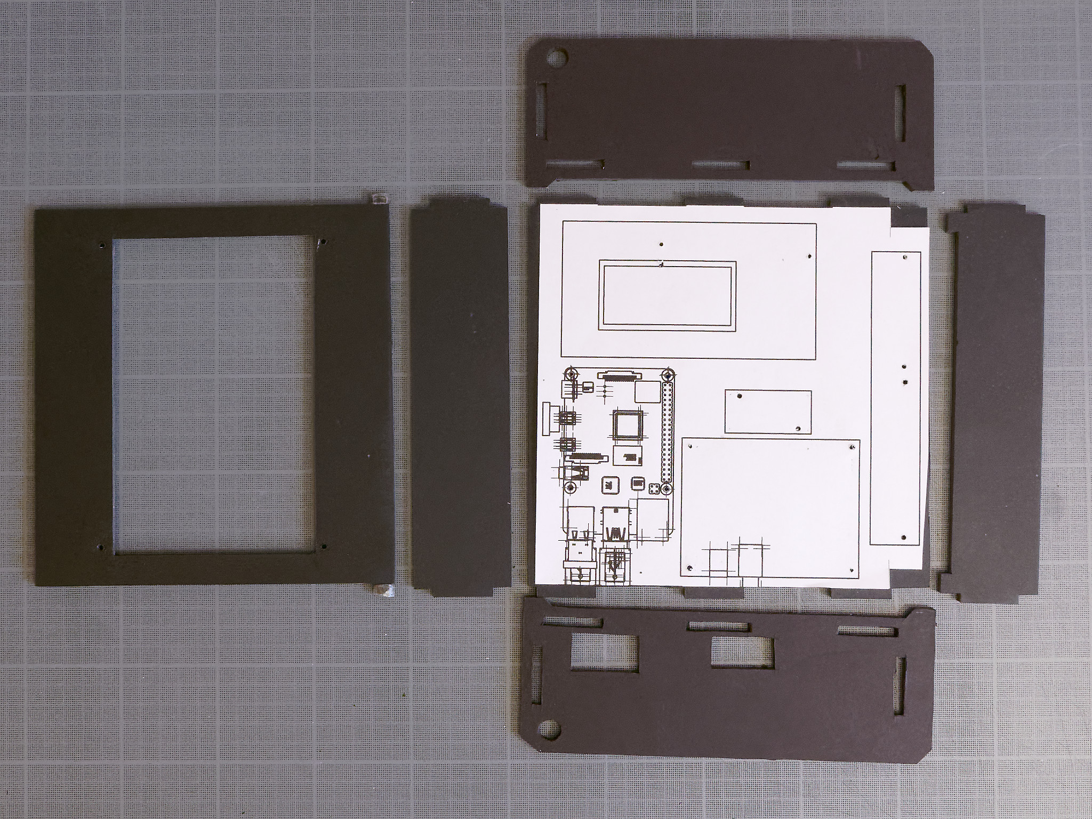
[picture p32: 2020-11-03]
docs/img/mount_short/echolab_box_step_01.jpg

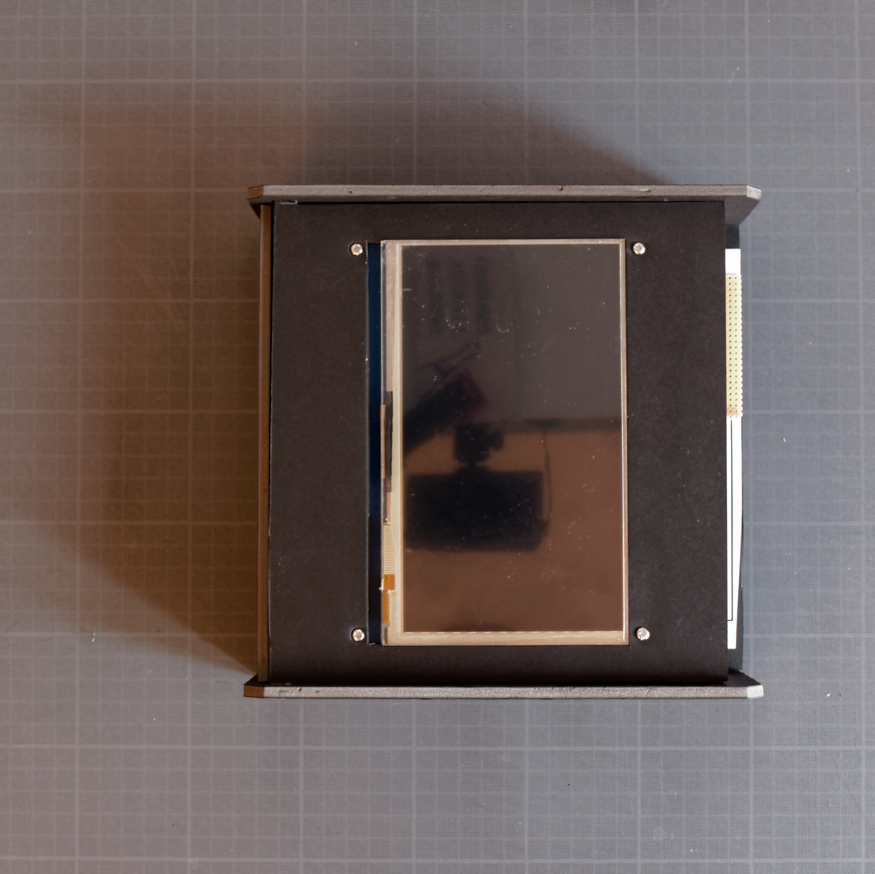
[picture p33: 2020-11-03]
docs/img/mount_short/echolab_box_step_19.jpg

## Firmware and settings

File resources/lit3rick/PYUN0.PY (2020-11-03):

#!/usr/bin/python
# -*- coding: utf-8 -*-
# -------------------------
# (c) kelu124
# GPLv3
# -------------------------

import json
import time
import datetime
import os,glob
import sys,re
import spidev
import numpy as np
import matplotlib.pyplot as plt

try:
    import RPi.GPIO as GPIO
except:
    print "Not loading RPi.GPIO as not on RPi"
    gpioexists = False
else:
    gpioexists = True

try:
    import pyexiv2
except:
    print "pyexiv2 does not exist on RPi"
    pyexivexists = False
else:
    pyexivexists = True



'''Description: Most updated library for the lit3rick platform. 
`20191023a` used to get the first good images on lit3rick =)
@todo: improve doc: http://sametmax.com/les-docstrings/
'''

__author__ = "kelu124"
__copyright__ = "Copyright 2018, Kelu124"
__license__ = "GPLv3"





##############
#
# RPI Part
#
##############

#================================================================================
class us_spi:
    """
       Creates a connection to the board.
       Used to acquire signals and store all acquisition parameters.
    """

    JSON = {}
    spi = spidev.SpiDev()

    JSON["firmware_md5"] = "fa6a7560ade6d6b1149b6e78e0de051f"
    JSON["firmware_version"] = "e_un0"
    JSON["data"] = []
    JSON["time"] = unicode(datetime.datetime.now())
    JSON["registers"] = {}
    JSON["registersHex"] = {}
    JSON["experiment"] = {}
    JSON["parameters"] = {}
    JSON["timings"] = {}
    JSON["experiment"]["id"] = str(datetime.datetime.now().strftime("%Y%m%d"))+"a"
    JSON["experiment"]["description"] = "na"
    JSON["experiment"]["probe"] = "na"
    JSON["experiment"]["target"] = "na"
    JSON["experiment"]["position"] = "na"
    JSON["V"] = "-1"

    f_ech = 0
    Nacq = 0
    LAcq = 0
    number_lines = 0
    verbose = True

    #--------------------------------------------------------------------------------
    def create_tgc_curve(self, init_value, final_value, curvetype):
        """
        Returns an arary with the TGC values, along a 40 values array.
        Used afterwards to set fpga registers.
        """
        n = 200/5
        dac_array = []
        for k in range(n+1):
            if curvetype:
                val = int(init_value+1.0*k*(final_value-init_value)/n)
            else:
                val = int((final_value-init_value)*k**3/n**3+init_value)
            dac_array.append(val)
        dac_array[-1] = 0
        dac_array[-2] = 0
        self.set_tgc_curve(dac_array)
        return dac_array, len(dac_array)


    #--------------------------------------------------------------------------------
    def set_timings(self, Pon,PdampOne, PHVneg, Poff, delay_acq, Acq):
        """
        Programs the sequence of Pon, Poff, Acquisition.
        """
        #t4 = WaitTill # 20us delay before acquisition
        # Pon,PdampOne, PHVneg, Poff, delay_acq, Acq
        #self.set_pulse_train(t1, t2, t3, t4, t5)
        self.set_pulse_train(Pon,PdampOne, PHVneg, Poff, delay_acq, Acq)
        # Some figures about the acquisitions now
        self.LAcq = (Acq-delay_acq)/1000 #ns to us
        self.Nacq = int(self.LAcq * self.f_ech * self.number_lines)
        self.JSON["timings"]["t1"] = Pon
        self.JSON["timings"]["t2"] = PdampOne
        self.JSON["timings"]["t3"] = PHVneg
        self.JSON["timings"]["t4"] = Poff
        self.JSON["timings"]["t5"] = delay_acq
        self.JSON["timings"]["t5"] = Acq
        self.JSON["timings"]["NAcq"] = self.Nacq
        self.JSON["timings"]["LAcq"] = self.LAcq
        self.JSON["timings"]["Fech"] = self.f_ech
        self.JSON["timings"]["NLines"] = self.number_lines
        
        print "NAcq = "+str(self.Nacq)
        if self.Nacq > 199999:
            raise NameError('Acquisition length over 200.000 points (8Mb = Flash limit)')
        return self.Nacq, self.LAcq, self.f_ech, self.number_lines



    #--------------------------------------------------------------------------------
    def set_multi_lines(self, Bool): # OK LIT3RICK
        """
        Determines if this is a single-line of multi-line acquisition.
        """
        if Bool:
            if self.verbose:
                print "Doing several lines.\nRemember to indicate how many lines. number_lines = 3 by default"
            self.write_fpga(0xEB, 1) # Doing one line if 0, several if 1
            self.number_lines = 3
        else:
            if self.verbose:
                print "Doing a single line"
            self.write_fpga(0xEB, 0) # Doing one line if 0, several if 1 
            self.number_lines = 1

    #--------------------------------------------------------------------------------
    def set_tgc_curve(self, tgc_values): # OK LIT3RICK
        """
        Sets up the TGC using an array
        """
        #print "Setting up the DAC curves"
        if len(tgc_values) < 43: # to correct
            for i in range(len(tgc_values)):
                if (tgc_values[i] >= 0) and (tgc_values[i] < 1020):
                    self.write_fpga(16+i, tgc_values[i]/4) # /4 since 1024 values, on 8 bits
                else:
                    self.write_fpga(16+i, 0)

    #----------------
    # FPGA Controls
    #----------------

    #--------------------------------------------------------------------------------
    def write_fpga(self, adress, value): # OK LIT3RICK
        """
        Basic function to write registers value to the FPGA
        """
        if gpioexists:
            self.spi.xfer([0xAA])
            self.spi.xfer([adress])
            self.spi.xfer([value])
        self.JSON["registersHex"][hex(adress)] = hex(value)
        self.JSON["registers"][int(adress)] = value

    #--------------------------------------------------------------------------------
    def set_ledRGB(self,R,G,B):
        self.write_fpga(0xC1, R) 
        self.write_fpga(0xC2, G) 
        self.write_fpga(0xC3, B) 
        #print "LEDs OK"


    #--------------------------------------------------------------------------------
    def init(self): # OK LIT3RICK
        """
        Initialises the FPGA
        """
        if gpioexists:
                GPIO.setmode(GPIO.BCM)
                # Once program is loaded, should be OK
                #for k in [3,4,17,27,5,12,16,20,15]:
                #    GPIO.setup(k, GPIO.IN)
                # @todo: reset from flash when flash works
                self.spi.open(0, 0) # CS0 is the FPGA, CS1 is flash
                self.spi.mode = 0b01
                self.spi.max_speed_hz = 100000 
                if self.verbose:
                    print "spi.cshigh is " + str(self.spi.cshigh)
                    print "spi mode is " + str(self.spi.mode)
                    print "spi maxspeed is "+str(self.spi.max_speed_hz)+"hz"
                self.set_ledRGB(0,1,0)
        else:
                print("Not running from a Raspberry Pi")

    #----------------
    # Testing functions
    #----------------

    #--------------------------------------------------------------------------------
    def test_spi(self, n_cycles): # OK LIT3RICK
        """
        Blinks the HILO n_cycles times.
        """
        self.set_ledRGB(0,0,1)


    #--------------------------------------------------------------------------------
    def set_hilo(self, HILO): # OK LIT3RICK
        """
        Sets HILO on TGC
        """
        if HILO:
            self.write_fpga(0xD8, 0x01) # 1: HILO ON
            print "HILO set HIGH"
        else:
            self.write_fpga(0xD8, 0x00) # 0: HILO OFF
            print "HILO set LOW"

    #--------------------------------------------------------------------------------
    def loop_spi(self):  # OK LIT3RICK
        """
        Pure debug test to spam SPI bus to have HILO LED blink continuously
        """
        while 1:
            self.write_fpga(0xD8, 0x01) 
            self.write_fpga(0xD8, 0x00) 


    #--------------------------------------------------------------------------------
    def loop_acq(self): # OK LIT3RICK
        """
        Pure debug test to spam SPI bus with loop acquisition.
        """
        while 1:
            self.write_fpga(0xEB, 0x00) # Doing 1 shot
            self.write_fpga(0xEF, 0x01) # Cleaning memory pointer
            self.write_fpga(0xEA, 0x0) # Software Trig : As to be clear by software
            time.sleep(0.001) # sleep 1ms


    #--------------------------------------------------------------------------------
    def ClearMem(self): # OK LIT3RICK
        """
        Reset RAM pointer
        """
        self.write_fpga(0xEF, 0x01) # To access memory

    #----------------
    # Setup functions
    #----------------
    #--------------------------------------------------------------------------------
    def set_msps(self, f_msps):
        """
        Setting acquisition speed.
        Using F, ADC speed is determined as 64Msps / (1 + f_msps)
        """
        self.write_fpga(0xED, f_msps)
        self.f_ech = float(64/((1+f_msps)))
        print "Acquisition frequency set at "+str(self.f_ech)+" Msps"
        return self.f_ech

    #--------------------------------------------------------------------------------
    def do_acquisition(self):
        """
        Doing an acquisition, trigs, then reads the data.
        """
        self.write_fpga(0xEF, 0x01) # Cleaning memory pointer
        self.JSON["time"] = unicode(datetime.datetime.now())
        self.write_fpga(0xEA, 0x01) # Software Trig : As to be clear by software
        self.JSON["data"] = []
        time.sleep(1) 
        milestone = self.Nacq / 5
        start = time.time()
        if gpioexists:
                for i in range(2*self.Nacq+2):
                    self.JSON["data"].append(self.spi.xfer([0x00])[0])
                    if not ((i+10)%milestone) and self.verbose:
                        print str((50*i)/self.Nacq)+"% - "+str(self.JSON["data"][-1])+" & "+str(self.JSON["data"][-2])
                end = time.time()
                delta = end - start
                if self.verbose:
                    print "Took %.2f seconds to transfer." % delta
                    print "for "+str(2*self.Nacq+2)+" transfers of data"
                self.JSON["N"] = new_n("./",self.JSON["experiment"]["id"])
                name_json = self.JSON["experiment"]["id"]+"-"+str(self.JSON["N"])+".json"
                with open(name_json, 'w') as outfile:
                    json.dump(self.JSON, outfile)
                self.JSON["data"] = []        
                #self.write_fpga(0xEF, 0x01) # Cleaning memory pointer
                #self.set_ledRGB(0,0,1)
                for p in range(0):
                    self.write_fpga(0xEF, 0x01) # Cleaning memory pointer
                    self.JSON["data"] = [] 
                    self.JSON["N"] += 1 
                    self.write_fpga(0xEF, 0x01) # Cleaning memory pointer
                    for i in range(2*self.Nacq+2):
                        self.JSON["data"].append(self.spi.xfer([0x00])[0])
                    name_json = self.JSON["experiment"]["id"]+"-"+str(self.JSON["N"])+".json"
                    with open(name_json, 'w') as outfile:
                        json.dump(self.JSON, outfile)

                if self.verbose:
                    print name_json+": file saved."
        else:
                print "Not on a RPI"
        return self.JSON["data"]

    #--------------------------------------------------------------------------------
    def do_acquisition_twice(self):
        """
        Doing an acquisition, trigs, then reads the data.
        """
        self.write_fpga(0xEF, 0x01) # Cleaning memory pointer
        self.JSON["time"] = unicode(datetime.datetime.now())
        self.write_fpga(0xEA, 0x01) # Software Trig : As to be clear by software
        self.JSON["data"] = []
        time.sleep(1)
        milestone = self.Nacq / 5
        start = time.time()
        if gpioexists:
                for i in range(2*self.Nacq+2):
                    self.JSON["data"].append(self.spi.xfer([0x00])[0])
                    if not ((i+10)%milestone) and self.verbose:
                        print str((50*i)/self.Nacq)+"% - "+str(self.JSON["data"][-1])+" & "+str(self.JSON["data"][-2])
                end = time.time()
                delta = end - start
                if self.verbose:
                    print "Took %.2f seconds to transfer." % delta
                    print "for "+str(2*self.Nacq+2)+" transfers of data"
                self.JSON["N"] = new_n("./",self.JSON["experiment"]["id"])
                name_json = self.JSON["experiment"]["id"]+"a-"+str(self.JSON["N"])+".json"
                with open(name_json, 'w') as outfile:
                    json.dump(self.JSON, outfile)
                if self.verbose:
                    print name_json+": file saved."
        else:
                print "Not on a RPI"
        
        self.write_fpga(0xEF, 0x01) # Cleaning memory pointer
        self.write_fpga(0xC2, 1) 
        self.JSON["time"] = unicode(datetime.datetime.now())
        self.JSON["data"] = []
        time.sleep(1)
        milestone = self.Nacq / 5
        start = time.time()
        if gpioexists:
                for i in range(2*self.Nacq+2):
                    self.JSON["data"].append(self.spi.xfer([0x00])[0])
                    if not ((i+10)%milestone) and self.verbose:
                        print str((50*i)/self.Nacq)+"% - "+str(self.JSON["data"][-1])+" & "+str(self.JSON["data"][-2])
                end = time.time()
                delta = end - start
                if self.verbose:
                    print "Took %.2f seconds to transfer." % delta
                    print "for "+str(2*self.Nacq+2)+" transfers of data"
                self.JSON["N"] = new_n("./",self.JSON["experiment"]["id"])
                name_json = self.JSON["experiment"]["id"]+"b-"+str(self.JSON["N"])+".json"
                with open(name_json, 'w') as outfile:
                    json.dump(self.JSON, outfile)
                if self.verbose:
                    print name_json+": file saved."
        else:
                print "Not on a RPI"

        return self.JSON["data"]


    #--------------------------------------------------------------------------------
    def set_acquisition_number_lines(self, n):
        """
        Sets the number of lines to acquire.
        """
        n_msb, n_lsb = n/256, 0x00FF&n
        self.write_fpga(0xEE, n_lsb)
        self.write_fpga(0xDE, n_msb)
        self.number_lines = n
        if self.verbose:
            print "Number of lines: "+str(n)

    #--------------------------------------------------------------------------------
    def set_HV(self, HVLevel):
        """
        Sets HV level
        """
        hv_msb, hv_lsb = HVLevel/256, 0x00FF&HVLevel
        self.write_fpga(0xD7, hv_lsb)
        self.write_fpga(0xD6, hv_msb)
        if self.verbose:
            print "HV Level: "+str(HVLevel)+" (/1Obits)"


    #--------------------------------------------------------------------------------
    def config_spi(self):
        """
        Initial configuration of the FPGA.
        """
        # Setup FPGA values by default
        self.set_pon(200)          # Set PulseOn
        self.set_pulses_delays()  # Set Lengh between Pon and Poff: 100ns
        self.set_poff(2000)        # Setting Poff 2us
        #set_tgc_constant(20, spi)   # gain at 20mV (2%)
        self.write_fpga(0xEC, 0x33) # Set DAC constant
        self.set_delta_acq(7000)    # 7us
        #write_fpga(0xEA, 0x00)     # Software Trig : As to be clear by software
        self.write_fpga(0xEB, 0x00) # 0: single mode 1 continious mode
        self.write_fpga(0xED, 0x03) # Frequency of ADC acquisition
        self.set_acquisition_number_lines(0xA0)      # How many cycles in countinious mode
        print "Config FPGA done!"

    #--------------------------------------------------------------------------------
    def set_tgc_constant(self, mV):
        """
        Setting TGC constant.
        """
        if mV > 1000:
            mV = 1000
        elif mV < 0:
            mV = 0
        hmV = mV/4
        print "Gain:", mV, " mV -- ", hex(hmV)
        self.write_fpga(0xEC, hmV) # Voltage gain control: 0V to 1V


    #--------------------------------------------------------------------------------
    def set_pon(self, p_on):
        if p_on > 2500:
            p_on = 2500
        elif p_on < 0:
            p_on = 0
        unit_p_on = int(p_on*128.0/1000)
        self.JSON["parameters"]["Pon"] = int(p_on)
        self.JSON["parameters"]["Pon_Real"] = int(unit_p_on*1000/128)
        print "POn width:", p_on, " ns -- ", hex(unit_p_on)
        self.write_fpga(0xE0, unit_p_on) # set sEEPon
        return unit_p_on*1000/128

    #--------------------------------------------------------------------------------
    def set_pon_neg(self, p_on_neg):
        if p_on_neg > 2500:
            p_on_neg = 2500
        elif p_on_neg < 0:
            p_on_neg = 0
        unit_p_on_neg = int(p_on_neg*128.0/1000)
        self.JSON["parameters"]["Pon_neg"] = int(p_on_neg)
        self.JSON["parameters"]["Pon_neg_Real"] = int(unit_p_on_neg*1000/128)
        print "PonNeg width:", p_on_neg, " ns -- ", hex(unit_p_on_neg)
        self.write_fpga(0xD4, unit_p_on_neg) # set sEEPon
        return unit_p_on_neg*1000/128

    #--------------------------------------------------------------------------------
    def set_pDampInt(self, pDampInt):
        if pDampInt > 2500:
            pDampInt = 2500
        elif pDampInt < 0:
            pDampInt = 0
        unit_p_damp_int = int(pDampInt*128.0/1000)
        self.JSON["parameters"]["Pon_neg"] = int(pDampInt)
        self.JSON["parameters"]["Pon_neg_Real"] = int(unit_p_damp_int*1000/128)
        print "PDampInt width:", pDampInt, " ns -- ", hex(unit_p_damp_int)
        self.write_fpga(0xD2, unit_p_damp_int) # set sEEPon
        return unit_p_damp_int*1000/128

    #--------------------------------------------------------------------------------
    def set_pulses_delays(self):
        PDELAYS = int(10/(1000/128.0))
        return PDELAYS*1000/128
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
if __name__ == "__main__":
    print "Loaded!"

    if len(sys.argv) > 1:
        if (sys.argv[1] == "-f" ) and (len(sys.argv) == 3) and (os.path.exists(sys.argv[2])):
            print("file exists - OK")
            UN0RICK = us_spi()
            UN0RICK.init()
            UN0RICK.set_multi_lines(True)
            UN0RICK.set_acquisition_number_lines(15) 
            UN0RICK = ConfigFromTxt(UN0RICK,sys.argv[2])
            UN0RICK.JSON["data"] = UN0RICK.do_acquisition()

        if "test" in sys.argv[1]:
            UN0RICK = us_spi()
            UN0RICK.init()
            UN0RICK.test_spi(3)

        if "single" in sys.argv[1]:
            UN0RICK = us_spi()
            UN0RICK.init()
            UN0RICK.test_spi(3)
            UN0RICK.set_HV(100)
            UN0RICK.set_hilo(0)
            TGCC = UN0RICK.create_tgc_curve(600, 600, True)[0]    # Gain: linear, 10mV to 980mV
            UN0RICK.set_tgc_curve(TGCC)                          # We then apply the curve
            UN0RICK.set_tgc_constant(100) #sets in mV from 0 to 1000 
            UN0RICK.set_period_between_acqs(int(2500000))        # Setting 2.5ms between shots
            UN0RICK.JSON["N"] = 1                                  # Experiment ID of the day
            UN0RICK.set_multi_lines(False)                       # Single acquisition
            UN0RICK.set_acquisition_number_lines(1)              # Setting the number of lines (1)
            UN0RICK.set_msps(0)                                  # Sampling speed setting
            A = UN0RICK.set_timings(200, 100, 120, 1000, 5000, 300000)# Settings the series of pulses
            UN0RICK.JSON["data"] = UN0RICK.do_acquisition()      # Doing the acquisition and saves
            UN0RICK.set_ledRGB(0,0,0)

        if "multi" in sys.argv[1]:
            UN0RICK = us_spi()
            UN0RICK.init()
            UN0RICK.test_spi(3)
            UN0RICK.JSON["N"] = 1 # Experiment ID
            UN0RICK.create_tgc_curve(600, 900, False)[0]  # Gain: expo, 300mV to 900mv
            #UN0RICK.set_tgc_curve(TGCC)                          # We then apply the curve
            UN0RICK.set_period_between_acqs(int(2500000))          # Setting 2.5ms between lines
            UN0RICK.set_multi_lines(True)                         # Multi lines acquisition        
            UN0RICK.set_acquisition_number_lines(10)              # Setting the number of lines (3)
            UN0RICK.set_msps(0)                                  # Sampling speed setting
            A = UN0RICK.set_timings(200, 100, 1000, 2000, 100000)# Settings the series of pulses
            UN0RICK.JSON["data"] = UN0RICK.do_acquisition()      # Doing the acquisition and saves

        if "process" in sys.argv[1]:
            make_clean("./")
            for MyDataFile in os.listdir("./data/"):
                if MyDataFile.endswith(".json"):
                    print MyDataFile
                    y = us_json()
                    y.show_images = False
                    y.JSONprocessing("./data/"+MyDataFile)
                    y.create_fft() 
                    y.save_npz() 
                    y.mkImg() 

        if "loop" in sys.argv[1]:
            UN0RICK = us_spi()
            UN0RICK.init()
            UN0RICK.set_multi_lines(True)                        # Multi lines acquisition
            UN0RICK.set_acquisition_number_lines(2)                 # Setting the number of lines
            UN0RICK.set_msps(3)                                  # Acquisition Freq
            A = UN0RICK.set_timings(200, 100, 2000, 5000, 200000)# Looping on triggers
            while True:
                UN0RICK.write_fpga(0xEA, 0x01)                   # trigs
                time.sleep(50.0 / 1000.0)                        # Waits 50ms between shots

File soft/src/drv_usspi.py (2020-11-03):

#!/usr/bin/env python3
#encoding: UTF-8

import time
import threading
import math
#import RPi.GPIO as GPIO
try: import spidev
except: None
import lib_helpers as hlp

#########################################
# Devices interface library
#########################################

#========================================
# US-SPI US transducer driver
#========================================
usspi_w = None
usspi_r = None
read_period = 0

params_desc = {
#----------------------------------------
    "":( "MIN", "DEFAULT", "MAX", "DIGIT"
              , "SIU_TO_RAW"
              , "RAW_TO_SIU"
              , "REGISTER", "BYTES"
              , "DESC"
              , "UNIT")

#----------------------------------------
  , "std_gain_db":( 0, 30, 80, 0
              , lambda siu: int(siu*(875-65)/80+65)
              , lambda raw: ...
              , 0, 2
              , "Value of static gain"
              , "dB")

#----------------------------------------
  , "gain_db":( 0, 30, 80, 0
              , lambda siu: int(siu*(875-65)/80+65)
              , lambda raw: ...
              , 0, 2
              , "Value of gain to be sent to US-SPI (0 to 80 db)"
              , "dB")

#----------------------------------------
  , "delay_us":( 0, 1, 1000, 0
              , lambda siu: int(siu / 0.025)
              , lambda raw: ...
              , 5, 2
              ,"Value of the delay (beginning of sampling windows the width of the sampling windows is fix at 200 microseconds"
              ,"µs")

#----------------------------------------
  , "compression_factor":( 0, 2, 2, 0
              , lambda siu: int(siu)
              , lambda raw: ...
              , 3, 1
              ,"0 -> sampling frequency (ex 80 MHz) , 1->sf/2 (40 MHz), 2->sf/4 (20MHz). It returns the maximum amplitude of the echo in the sampling period /!\ Compression is available only if Filter=4(NoFilter) AND SamplingFreq=1(80MHz)"
              ,"")

#----------------------------------------
  , "tension_v":( 10, 20, 250, 0
              , lambda siu: int(siu*(98/180)+81.7)
              , lambda raw: ...
              , 6, 1
              ,"Voltage of the transmitter pulse"
              ,"V")

#----------------------------------------
  , "freq_mhz":( 1, 3.5, 20, 3
              , lambda siu: int((1000/(2*siu)-27)/6.5)
              , lambda raw: ...
              , 7, 1
              ,"Frequency of the transmitter pulse in MHZ (between 1MHz and 20 MHz) pulse will be period/2"
              ,"MHz")

#----------------------------------------
  , "prf_hz":( 100, 100, 2000, 0
              , lambda siu: int((1000000/siu)/0.025)
              , lambda raw: ...
              , 8, 3
              ,"Frequency of the line pulse in Hz (between 100Hz and 2kHz)"
              ,"Hz")

#----------------------------------------
  , "filter_no":( 0, 4, 4, 0
              , lambda siu: int(siu)
              , lambda raw: ...
              , 14, 1
              ,"Frequency of the filter (0=1.25MHz, 1=2.5MHz, 2=5MHz, 3=10MHz, 4=No filter)"
              ,"")

#----------------------------------------
  , "nb_samples":( 1, 1000, 4000, 0
              , lambda siu: int(siu)
              , lambda raw: ...
              , -1, 0
              ,"Number of samples to be acquired"
              ,"")

#----------------------------------------
  , "dual_transducer":( 0, 0, 1, 0
              , lambda siu: int(siu)
              , lambda raw: ...
              , 9, 1
              ,"Transmission/ reflexion (single or dual crystals) 0 - single crystal, 1 - dual crystals"
              ,"")

#----------------------------------------
  , "ascan_scale":( 0, 4000, 65532, 0
              , lambda siu: int(siu)
              , lambda raw: ...
              , 10, 2
              ,"Scale (duration) of the A-scan in step of 25ns"
              ,"25ns")

#----------------------------------------
  , "echo_polarity":( 0, 50, 256, 0
              , lambda siu: int(siu)
              , lambda raw: ...
              , 13, 1
              ,"Polarity"
              ,"")

#----------------------------------------
  , "dac_off":( 0, 1, 1, 0
              , lambda siu: int(siu)
              , lambda raw: ...
              , 11, 1
              ,"DAC for TGC 0 ON, 1 OFF"
              ,"")

#----------------------------------------
  , "reload_on_sample":( 0, 4000, 65532, 0
              , lambda siu: int(siu)
              , lambda raw: ...
              , 4, 2
              ,"Sample auto-reload : when you will read the Xth samples, the US-Key will store AUTOMATICALLY the current A-scan inside its FIFO"
              ,"")
  
#----------------------------------------
  , "sampling_freq":( 0, 1, 2, 0
              , lambda siu: int(siu)
              , lambda raw: ...
              , 24, 1
              ,"Sampling Freq : 0=160MHz / 1=80MHz / 2=40MHz"
              ,"")
  
#----------------------------------------
  , "echo_start_pos":( 0, 0, 65535, 0
              , lambda siu: int(siu)
              , lambda raw: raw
              , 12, 2
              ,"?????"
              ,"")
  
#----------------------------------------
  , "echo_start_width":( 0, 10000, 65535, 0
              , lambda siu: int(siu)
              , lambda raw: raw
              , 12, 2
              ,"?????"
              ,"")
  
  }

raw_params =  hlp.build_raw_params(params_desc)

#----------------------------------------
# Initialize SPI port
#----------------------------------------
def open_spi():
  global usspi_w
  global usspi_r

#  GPIO.setwarnings(False)
#  GPIO.setmode(GPIO.BOARD)
#  GPIO.setup(3, GPIO.OUT, initial = GPIO.LOW)
  try:
    usspi_w = spidev.SpiDev(0, 0)  
    usspi_w.max_speed_hz = 8000000 	# 1 MHz max, boosted to 8MHz !!!
    usspi_w.mode = 0b01 			# CPOL=0 CPHA=1
  except:
    usspi_w = None

  try:
    usspi_r = spidev.SpiDev(0, 1)  
    usspi_r.max_speed_hz = 8000000	# 1 MHz max, boosted to 8MHz !!!
    usspi_r.mode = 0b01 			# CPOL=0 CPHA=1 
  except:
     usspi_r = None

#----------------------------------------
# Write byte array on SPI port
#----------------------------------------
def write_spi(wBuffer):
  global usspi_w

  # print(wBuffer)
  if usspi_w:
    usspi_w.writebytes(wBuffer)

#----------------------------------------
# Write byte array on SPI port
#----------------------------------------
def read_spi(count):
  global usspi_r

  if usspi_r:
    return usspi_r.readbytes(count)
  else:
    return [math.sin(i/5)*100+128 for i in range(count)]

#----------------------------------------
# Initialize SPI port
#----------------------------------------
def close_spi():
  global usspi_w
  global usspi_r

  if usspi_w:
    usspi_w.close()
  if usspi_r:
    usspi_r.close()
#  GPIO.cleanup()
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
